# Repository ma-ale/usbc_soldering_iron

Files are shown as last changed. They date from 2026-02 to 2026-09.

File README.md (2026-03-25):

# USB-C Soldering Iron

Repo for a cool usb-c soldering iron that uses C245 cartridges and power up to 130W.

Read the [project report](doc/report/README.md) (in italian).

# IDEAS

* USB-C connector on the edge of the PCB like the [alientek T90B](https://youtu.be/Xl0IKpvlF3Y?si=ecKIGLwI0vSPZbJ4&t=7) (clamping plate)
* OLED Screen on a separate PCB, same project with a V-Cut
* More compact tip recess, stabilized by a, aluminium ring, maybe bought at the hardware store
* Single screw disassembly
* 13mm grip dimensions and 18mm otherwise
* 1mm walls in PETG
* Add a ~small~ button to the bootsel line

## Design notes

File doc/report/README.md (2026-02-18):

# Project Report

Obbiettivi:

- Supporto USB PD 3.1 e EPR per una potenza massima di 130W@28V.
- Usare un filtro per rimanere al di sotto dei 5A massimi che supporta lo standard.
- Usare le [cartucce C245](CARTRIDGE.md) della JBC e compatibili.
- Mantenere la scheda sotto i 10x10mm di dimensioni per approfittare dei bassi costi di produzione.
- Creare una shell stampabile in 3D.

## Progetti Simili

- [EJ-Sil](https://github.com/Ralim/IronOS/discussions/2080): usa le punte del pinecil e la differenza principale è l'utilizzo di mosfet a canale n per lo switching della punta.
- [Arduino Soldering Station](https://www.instructables.com/DIY-Arduino-Soldering-Station/): progetto di GreatScott, si alimenta dalla tensione di rete e usa i manici JBC e punte C245.
- [Unisolder](http://dangerousprototypes.com/forum/index.php?topic=7218.0): stazione completamente universale per molteplici tipi di punte, anche questa da banco.
- [Axxsolder](https://github.com/nx6110a5100/Stm32-jbc-solder-station): stazione portatile, alimentabile anche con usb-c ma a 60W massimi, compatibile con punte C245 e C210.

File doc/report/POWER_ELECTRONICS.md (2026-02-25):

# Circuiteria di Potenza

La parte principale del saldatore è la parte di potenza.

## USB PD
Lo standard USB PD e EPR permette potenze di uscita fino a 280W, il problema è che l'aumento di potenza viene ottenuto solamente con un aumento di tensione, mantenendo la corrente massima a 5A:
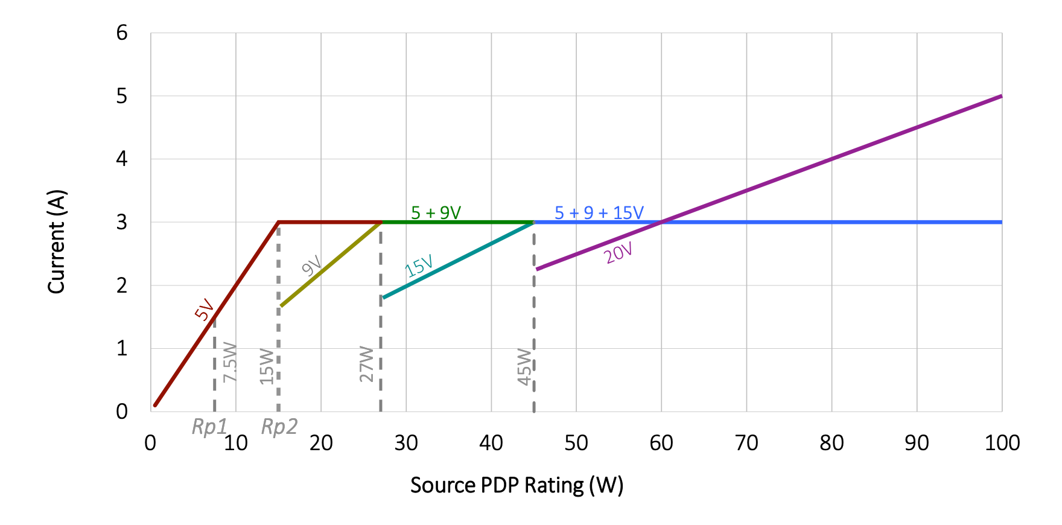
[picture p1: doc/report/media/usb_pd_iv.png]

Quindi per mantenere la potenza di ingresso al di sotto del rating dell'alimentatore è necessario mantenere la corrente al di sotto dei 5A, superare i 5A (o poco più) manderebbe l'alimentatore in protezione spengendolo.
La maggior parte dei saldatori commerciali USB non hanno nessun tipo di filtraggio, invece usano diversi trucchi:

1. Punte non standard a 5Ohm, come il [Sequre S99](https://sequremall.com/products/sequer-s99-soldering-iron-support-pd-qc-dc-pps-power-supply-compatible-with-c245-tip-for-drone-rc-model-welding-repair-tool-anti-stat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).
2. Switching molto veloce.
3. Limitano la tensione di ingresso per rimanere sotto al limite di corrente, limitando anche la potenza.
4. Se ne fregano il cazzo e sperano che l'alimentatore se ne freghi anch'esso.

## Monitoring della Potenza di Uscita

Tocca leggere sia la tensione che la corrente, per la lettura della tensione basta un partitore resistivo:
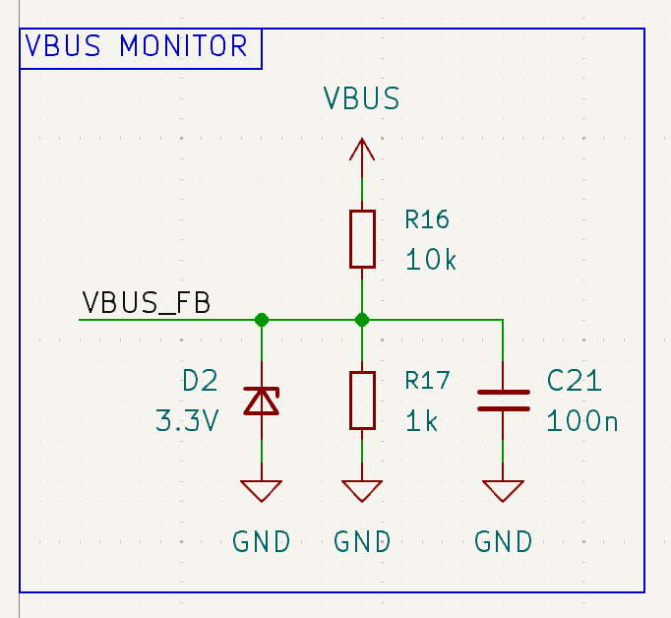
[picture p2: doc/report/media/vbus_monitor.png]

Mentre per la lettura della corrente conviene usare un monitor high-side, in modo da non disturbare la trensione di terra e quindi le misure della termocoppia. Questi amplificatori devono essere fatti apposta per sopportare la tensione a modo comune alta, pari alla tensione di alimentazione.
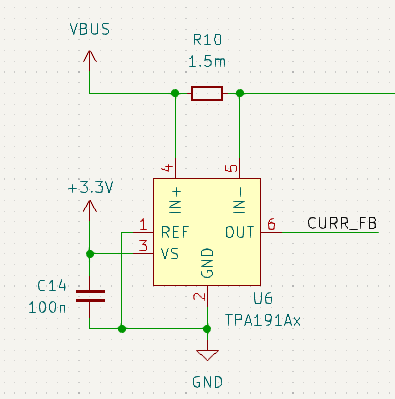
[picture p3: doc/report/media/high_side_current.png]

Questo tipo di monitoring si può fare in diversi modi:

1. Con un amplificatore operazionale discreto, ma questo porta il numero di componenti ad almeno 5, contando condensatore di bypass e resistenza di uscita sono 7.
2. Con un integrato con uscita di corrente come lo [ZXCT1109](https://www.diodes.com/part/view/ZXCT1109), che però ha una uscita in corrente che per essere letta correttamente dovrebbe essere bufferata.
3. Con un integrato con uscita in tensione come lo [TPA191](https://static.3peak.com/res/doc/ds/Datasheet_TPA191.pdf), in questo caso non serve resistenza di gain e basta attaccarlo al pin di ADC del micro.
4. Usar un integrato con uscita digitale come lo [INA230](https://www.ti.com/lit/ds/symlink/ina230.pdf) o l'[INA226](https://www.ti.com/lit/ds/symlink/ina226.pdf), che integra sia il monitoring di tensione che quello di corrente, però il costo è molto più alto.

Analisi costo/area:

- INA226: 0.61 EUR, solo area di un MSOP-10, non poca ma tutto in uno.
- TPA191 + 1k.1% + 10k.1% + Zener: 0.57 EUR, area 3x0603+SOD-323+SOT-23-6, leggermente maggiore ma migliore flessibilità sul piazzamento.

Per evitare di comprare altri componenti e aumentare inutilmente il costo dell'ordine è meglio usare il [INA226](https://www.ti.com/lit/ds/symlink/ina226.pdf) o il suo equivalente [TPA626](https://www.lcsc.com/product-detail/C5761471.html). Inoltre questi integrati permettono di impostare alert per la sovraccorrente o sovratensione.
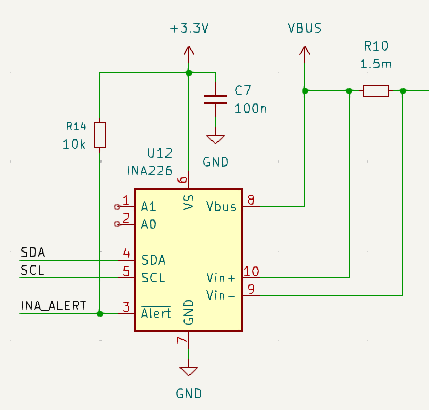
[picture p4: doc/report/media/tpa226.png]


## Mosfet e Filtro Pi
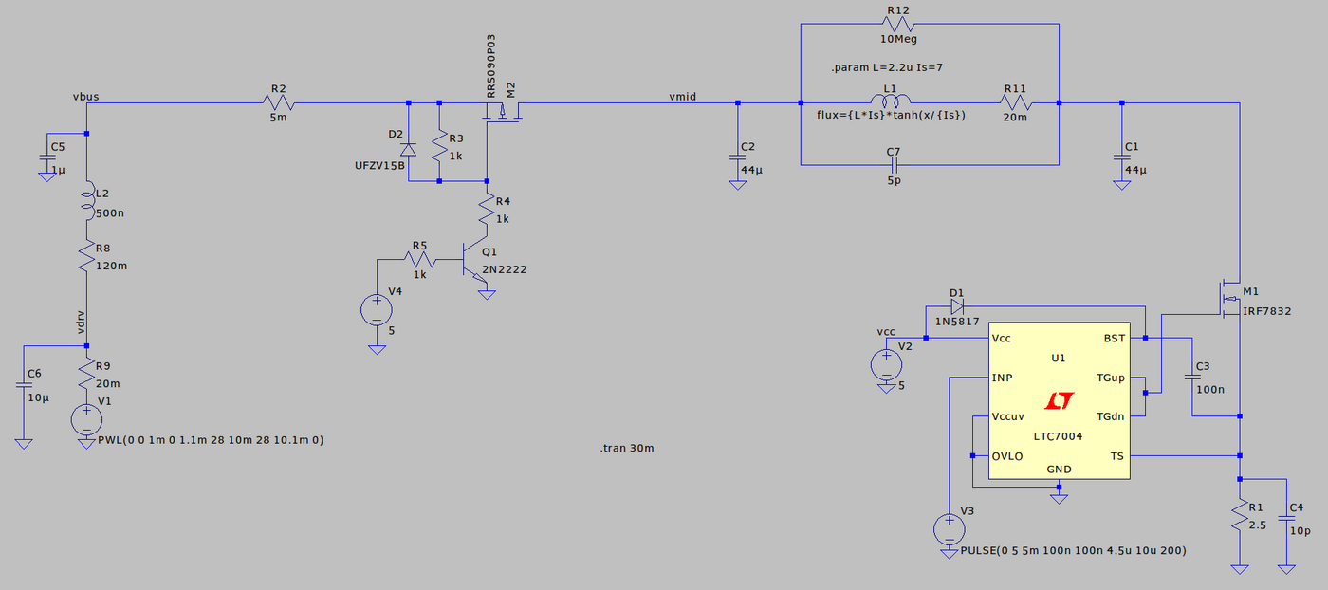
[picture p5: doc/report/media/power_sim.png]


Quello che importa è avere una corrente costante dal lato di ingresso, siccome la punta è un carico resistivo mi importa poco se riceve picchi di tensione e corrente. Per questo motivo il modo più semplice di smussare la corrente al lato di ingresso è di usare un [filtro PI](https://resources.altium.com/it/p/pi-filter-designs-power-supplies):
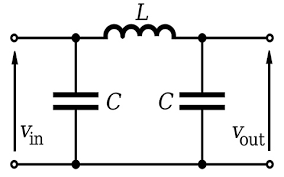
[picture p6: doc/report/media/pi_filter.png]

La frequenza di taglio del filtro PI è la solita di un filtro LC:
$$
f_0 = \frac{1}{2\pi\sqrt{L\ 2C}}
$$
Allora per ottenere il comportamento desiderato la frequenza di switching della punta deve essere almeno una decade sopra questo valore.
$$
L=2.2\mu \text{H},\ C=44\mu \text{F} \\ f_0 = 11.4\text{kHz}
$$
La frequenza di switching va anche valutata in base alle perdite di switching sul mosfet.

A differenza di [altre soluzioni](#altre-soluzioni), un filtro di questo tipo è di bassissima complessità e non richiede un particolare controllo, l'importante è usare la giusta frequenza di switching e limitare la potenza alla punta per garantire che la corrente rimanga nel limite. 

### Scelta dell'Induttore

Le specifiche principali dell'induttore per questa applicazione sono:

- Dimensione, la scheda è in alcune sezioni di 10mm di larghezza, quindi sarebbe meglio tenersi sotto i 6x6mm.
- ESR (Equivalent Series Resistance), ci dice quanto dissiperà l'induttore, inversamente proporzionale a dimensione e all'induttanza.
- Corrente di saturazione, la corrente per la quale il core dell'induttore satura, superare questa corrente riduce l'induttanza effettiva e scalda il core.
- Corrente di riscaldamento, la corrente per cui l'induttore comincia a scaldarsi sopra una certa temperatura se l'aria è a 25 gradi, ci dice la resistenza termica del package.

Alcuni induttori considerati, in **bold** quelli buoni:
| **MODELLO** | **VALORE** | **DCR** | **PACKAGE** |
| --- | --- | --- | --- |
| [XAL6060-103MEC](https://www.lcsc.com/product-detail/C5329540.html) | 10u | 27m | 6.6x6.4 |
| [XRFWHP0660A-100M](https://www.lcsc.com/product-detail/C51913009.html) | 10u | 30m | 6.6x6.4 |
| [AAPS0660M100F](https://www.lcsc.com/product-detail/C49261494.html) | 10u | 30m | 6.6x6.4 |
| [XRFWHP0660A-4R7M](https://www.lcsc.com/product-detail/C51913007.html) | 4.7u | 15m | 6.6x6.4 |
| [APH0660C-4R7M-TCD5](https://www.lcsc.com/product-detail/C50326286.html) | 4.7u | 15m | 6.6x6.4 |
| [AAPS0660M4R7F](https://www.lcsc.com/product-detail/C49261490.html) | 4.7u | 15m | 6.6x6.4 |
| [APS0660M4R7F](https://www.lcsc.com/product-detail/C49261301.html) | 4.7u | 15m | 6.6x6.4 |
| **[FC-ALX 4030D-2R2MT](https://www.lcsc.com/product-detail/C5370906.html)** | **2.2u** | **11m** | **4.2x4.2** |
| [MTQH404030S2R2MBT](https://www.lcsc.com/product-detail/C50345893.html) | 2.2u | 23m | 4.2x4.2 |
| [PSTMAA4030-2R2MG](https://www.lcsc.com/product-detail/C45385247.html) | 2.2u | 22m | 4.2x4.2 |
| [XRIM404030S2R2MGCA](https://www.lcsc.com/product-detail/C39846868.html) | 2.2u | 19m | 4.2x4.2 |
| [FC-ALX 5030D-3R3MT](https://www.lcsc.com/product-detail/C5370911.html) | 3.3u | 17m | 5.3x5.1 |
| [FC-ALX 5030D-2R2MT](https://www.lcsc.com/product-detail/C5370910.html) | 2.2u | 12m | 5.3x5.1 |

### Scelta dei Condensatori

[Derating](https://www.microtype.io/blog/dc-bias-effect-in-ceramic-capacitors) per DC bias.
[Modelli](https://product.tdk.com/en/technicalsupport/tvcl/general/mlcc.html) fatti bene della TDK. [Modelli](https://www.chemi-con.co.jp/en/faq/detail.php?id=How2LTspice) della Chemicon.

### Corrente di Inrush
### MOSFET e Driver

La scelta dei mosfet è fondamentale per ridurre la potenza dissipata, per semplificare il sistema ho scelto di usare uno [switching high-side](https://techweb.rohm.com/product/power-device/switches/23727/), mentre per ridurre le perdite sul mosfet ho deciso di usare un canale N. 
I mosfet canale N hanno resistenza di canale minore e minore carica di gate, quindi permettono di minimizzare sia le perdite di conduzione che le perdite di commutazione. Il problema è che usare un mosfet a canale n in configurazione high side richiede un driver fatto apposta.

Le perdite a causa della conduzione del mosfet si calcolano con l'espressione:
$$
P_\text{cond} = \frac{I^2}{R_{\text{DS}_\text{on}}} D
$$
Dove $I$ è la corrente che scorre nel mosfet quando acceso, approssimabile come $I=V_\text{BUS}/R_\text{tip}$, $T$ è il periodo di commutazione e $D$ è il duty cycle.

    NOTA: si arriva ad una espressione migliore se si considera che pure D dipende dalla potenza che voglio alla punta

Mentre la potenza persa durante la commutazione è stimabile come:
$$
P_\text{SW} = \frac{I\ V_{\text{BUS}}\ t_{\text{SW}}\ f}{2}
$$
Dove $t_\text{SW} = t_r + t_f$ è la somma del tempo di commutazione alto e basso del mosfet, si ricava dalla corrente di uscita del driver e dalla carica di gate del mosfet.

Lista di MOSFET canale n buoni:
|**MODELLO**|**VDS**|**RDSon**|**Qg [C]**|
|---|---|---|---|
|[AGM6014AP](https://www.lcsc.com/product-detail/C6719405.html)|60|4.3m|33n|
| [CSD18543Q3A](https://www.lcsc.com/product-detail/C840100.html) | 60 |  8.1m  |  11.1n |
| [AGM403AP](https://www.lcsc.com/product-detail/C7466527.html) |  40  | 2.7m | 10n |
| [AGM312AP](https://www.lcsc.com/product-detail/C22364314.html) | 30 | 9m | 4.1n |
| [AON7544](https://www.lcsc.com/product-detail/C315567.html) | 30 | 5m | 22.5n |
| [60N04D](https://www.lcsc.com/product-detail/C7543822.html) | 40 | 6.9m | 5.8n |
| [HD304N070SG](https://www.lcsc.com/product-detail/C50132379.html) | 40 | 6.5m | 16n |
| [TMG0069N04DF](https://www.lcsc.com/product-detail/C19189166.html) | 40 | 6.9m | 5.8n |
| [DOZ55N04](https://www.lcsc.com/product-detail/C42420928.html) | 40 | 5m | 19.5n |

Lista di driver buoni e non:
| **LINK** | **NOTE** | **PACKAGE** | **DIODO BOOT** |
| --- | --- | --- | --- |
| https://www.lcsc.com/product-detail/C5795658.html | half bridge, consigliato per notebook e quindi tensione minore | dfn 2x2 |  |
| https://www.lcsc.com/product-detail/C116731.html | half bridge per buck | dfn 2x2 |  |
| https://www.lcsc.com/product-detail/C892859.html | half bridge per buck | dfn 2x2 |  |
| https://www.lcsc.com/product-detail/C606336.html | half bridge per buck | dfn 3x3 |  |
| https://www.lcsc.com/product-detail/C533032.html | low-side ma anche high-side con configurazione strana, input differenziale | sot 23 |  |
| https://www.lcsc.com/product-detail/C5481755.html | high e low-side per mosfet SiC, input differenziale e configurazione strana | sot 23 |  |
| https://www.lcsc.com/product-detail/C964602.html | half bridge per buck | dfn 2x2 | interno |
| https://www.lcsc.com/product-detail/C2677203.html | logica 5V | sot 23 | esterno |
| **[IRS10752LTRPBF](https://www.lcsc.com/product-detail/C126923.html)** |  | sot 23 | esteno |
| [IRS20752LTRPBF](https://www.lcsc.com/product-detail/C495818.html) |  | sot 23 | esterno |
| [IRS25752LTRPBF](https://www.lcsc.com/product-detail/C538346.html) |  | sot 23 | esterno |
| **[NSG10752](https://www.lcsc.com/product-detail/C41414522.html)** | pin-compatible con quelli infineon | sot 23 | esterno |
| https://www.lcsc.com/product-detail/C603811.html | half-bridge per buck, discontinuato | dfn 2x2 | interno |
| https://www.lcsc.com/product-detail/C603810.html | half bridge per buck, versione di replacement per NCP81161 | dfn 2x2 | interno |
| https://www.lcsc.com/product-detail/C2677131.html | half bridge per buck | dfn 3x3 | interno |
| https://www.lcsc.com/product-detail/C41414473.html | half bridge per buck | dfn 3x3 | esterno |
| https://www.lcsc.com/product-detail/C154581.html | half bridge per buck | dfn 3x3 | interno |

Il problema dei driver selezionati è che hanno una UVLO molto alta (10V) che quindi richiede un buck ulteriore per alimentarli, aumentando il costo e numero dei componenti.

## Altre Soluzioni

## Altri Saldatori

È comodo confrontare altri saldatori USB-C e vedere come funzionano.

### Pinecil V2
Link alla [wiki](https://wiki.pine64.org/wiki/Pinecil), [schema elettrico](https://files.pine64.org/doc/Pinecil/Pinecil_schematic_v2.0_20220608.pdf).

### Alientek T80P
[Teardown](https://www.reddit.com/r/soldering/comments/1cm03vg/jbc_style_usb_soldering_iron_roundup_teardown/ ), [issue di IronOS](https://github.com/Ralim/IronOS/issues/1945) con foto e lista componenti.

### Miniware TS21
[Teardown](https://www.reddit.com/r/soldering/comments/1kho3lc/miniware_ts21_disassemble/), [issue di IronOS](https://github.com/Ralim/IronOS/issues/2122) con componenti.

### Sequre S60P
[Teardown](https://community.element14.com/technologies/test-and-measurement/b/blog/posts/usb-c-soldering-iron-quick-review-sequre-s60) e dettagli dei componenti, [discusione su IronOS](https://github.com/Ralim/IronOS/discussions/1806).

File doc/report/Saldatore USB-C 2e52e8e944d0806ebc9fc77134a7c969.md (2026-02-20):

# Saldatore USB-C

- https://www.printables.com/model/1127227-gridfinity-alientek-t80t80p-tool-holder-5x1 modello di un holder gridfinity per il t80p, possibile usarlo per confrontare le dimensioni delle punte
- https://www.printables.com/model/1548831-miniware-ts21/files modello a dimensione vera di un ts21, utile per confrontare le dimensioni
- https://www.printables.com/model/1435424-sliding-box-for-miniware-ts21 case per ts21 con storage per punte

# Buck

- [https://www.monolithicpower.com/en/inductor-selector-tool](https://www.monolithicpower.com/en/inductor-selector-tool)
- [Selecting Inductors for Buck Converters](https://www.ti.com/lit/an/snva038b/snva038b.pdf?ts=1769296550256)
- https://it.wikipedia.org/wiki/Convertitore_buck

i.sstatic.net

## Versione con Buck Discreto

Una soluzione sarebbe di costruire un buck sincrono con componenti discreti

[Basic Calculation of a Buck Converter's Power Stage](https://www.ti.com/lit/an/slva477b/slva477b.pdf?ts=1769211977943)

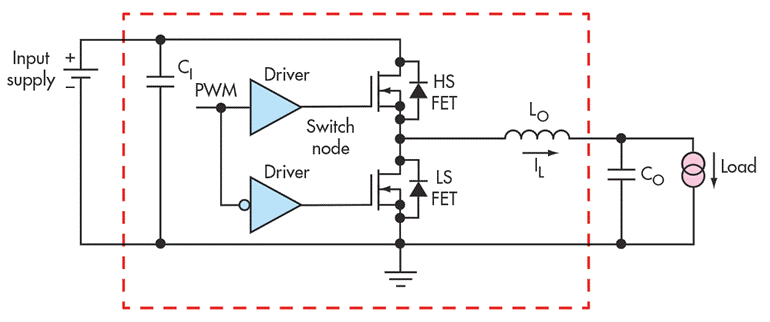
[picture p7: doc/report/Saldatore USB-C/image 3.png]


### MOSFET

Meglio usare un doppio mosfet integrato in configurazione half-bridge. Esistono tipi con due N-MOS e tipi con P-MOS e N-MOS. La versione con due N-MOS è la migliore in termini di efficienza ma richiede necessariamente un driver particolare con circuito di bootstrap.

Alcuni MOSFET:

- https://www.lcsc.com/product-detail/C155503.html
- https://www.lcsc.com/product-detail/C3289384.html
- https://www.lcsc.com/product-detail/C485677.html
- https://www.lcsc.com/product-detail/C464808.html
- https://www.lcsc.com/product-detail/C269268.html

### Driver

Esistono diversi driver, per questo caso servono driver o half-bridge oppure apposta per buck sincroni, il primo richiede due segnali PWM per controllare ognuno dei mosfet separatamente, mentre il secondo accetta un solo segnale PWM.

Una specifica importante è la corrente di uscita che determina il tempo di switching dei mosfet. Vedi [questa presentazione](https://www.mouser.com/pdfdocs/Selecting-Gate-Driver-Tutorial.pdf) per capire di cosa si parla, ma deriva dalla velocità con cui si riempie la capacità di gate. 

Alcuni Driver:

- https://www.lcsc.com/product-detail/C2676972.html https://www.lcsc.com/product-detail/C460680.html
- [IR3537 / CHL8510](https://www.lcsc.com/datasheet/C537661.pdf)
- https://www.lcsc.com/product-detail/C603956.html?s_z=n_NCV51511

## Versione con Buck Integrato

Si può usare un buck integrato (switch e controllore) e regolare la tensione di feedback con il microcontrollore, ottenendo la tensione che volgio io.

https://www.youtube.com/watch?v=hyLYPu-4EN8

Non è una cosa troppo comune ne tanto facile da fare, alcuni dicono che con l’ADC del micro non si va da nessuna parte, altri dicono di si ma di usare un ADC in corrente. Alcuni riferimenti:

- https://forum.allaboutcircuits.com/threads/digitally-controlled-buck-converter.75554/
- https://www.ednasia.com/use-a-current-mirror-to-control-a-power-supply/
- https://electronics.stackexchange.com/questions/700494/mcu-controlled-buck-converter-ic

Uno dei problemi di questo approccio è che i buck commerciali, anche di alta potenza sono fatti per essere “buoni”, poco ripple e tensione molto precisa. Mentre qello che serve a me è di rimanere sotto la potenza nominale impostata, quindi è molto overkill. Inoltre molti dei buck di alta potenza usano molti componenti di contorno aumentando ancora il prezzo.

Ricerca su Gemini: https://gemini.google.com/app/65933a590936e3ec

Lista di buck fighi:

- [SiC461](https://www.lcsc.com/datasheet/C499531.pdf) la Vishay ha addirittura un calcolatore fatto apposta: https://vishay.transim.com/landing
- [~~SY8308~~](https://www.lcsc.com/datasheet/C7427429.pdf) https://www.lcsc.com/product-detail/C125897.html, https://www.lcsc.com/product-detail/C207642.html
- [AOZ2261AQI](https://www.lcsc.com/datasheet/C2071876.pdf)
- [XR76203](https://www.lcsc.com/datasheet/C555356.pdf) da usare il [xr76208](https://www.lcsc.com/product-detail/C555356.html?s_z=n_xr76208)
- https://www.lcsc.com/product-detail/C3188410.html [Datasheet in inglese](https://www.ti.com/lit/ds/symlink/lm61495-q1.pdf?ts=1770121316572)
- [NDP13802QB](https://www.lcsc.com/datasheet/C7420577.pdf) oppure https://www.lcsc.com/product-detail/C7420585.html?s_z=n_ndp1480
- [TPS56837Hx](https://www.ti.com/lit/ds/symlink/tps56837h.pdf?ts=1769345326940) …HA non ha il discharge ma costa di più

Saldatori che usano questo metodo: 

- Solder ninja pen, [hardware](https://github.com/sitronlabs/Solder-Ninja-Pen-Electronics), [software](https://github.com/sitronlabs/Solder-Ninja-Pen-Firmware), [ironos](https://github.com/Ralim/IronOS/issues/1989). Soli 45W ma usa un buck integrato [TPS621351](https://www.lcsc.com/product-detail/C2070706.html?s_z=n_TPS621351) quindi il software di controllo è quello. Usa questo DAC ([DAC5311](https://www.lcsc.com/product-detail/C191582.html?s_z=n_DAC5311)) per controllare il feedback del buck.
- [iFixit Hub](https://www.ifixit.com/Device/iFixit_Soldering) le [schematic](https://www.ifixit.com/Document/WOhhObf5OxsyA4Xh/ES-SI-2100-R15.pdf?referrer=wiki%3A570611) sono pubbliche, 100W ma dalle recensioni non sembra arrivarci davvero. Usa un [MP2329](https://www.monolithicpower.com/en/mp2329.html) buck fino a 20V di Vin e il dac integrato dell’STM32 per controllare il feedback. Le dimensioni del controllore sono piccole, forse per questo non riesce ad arrivare ai 100W senza andare in protezione.

## Versione con Half-Bridge e Micro

La differenza di questo approccio è l’uso di un half-bridge che però ha anche integrato il driver per i mosfet. In questo modo l’interità del controllo deve essere fatta dal microcontrollore però si risparmia sulle feature inutili e tutti i componenti di contorno che ne vengono.

Alcuni MOSFET:

- https://www.lcsc.com/product-detail/C3654920.html?s_z=n_SiC641

Ricerca su Gemini: https://gemini.google.com/app/7377e4ba09fedab9

Calcolo dell’efficienza:

- https://fscdn.rohm.com/en/products/databook/applinote/ic/power/switching_regulator/buck_converter_efficiency_app-e.pdf
- https://www.ti.com/lit/an/slvaeq9/slvaeq9.pdf?ts=1769284164843&ref_url=https%253A%252F%252Fwww.google.com%252F
- https://www.hajim.rochester.edu/ece/sites/friedman/papers/ICECS_10.pdf

## Buck Multifase

Per ridurre il picco di corrente dall’ingresso bisogna necessariamente aggiungere più buck in parallelo. 

https://www.ti.com/lit/an/slva882b/slva882b.pdf

Il picco di corrente di un buck è pari alla corrente media di uscita più la metà del ripple di corrente, che per design è maggiore al 40%. Quindi a livello di corrente di picco non si è migliorato nulla.

Nel buck multifase il picco di corrente è diviso per il numero di fasi, quindi per me ne bastano due.

L’implementazione di un buck multifase, per essere abbastanza compatta, deve essere fatta o con power stage integrati controllati dal microcontrollore, o in modo discreto con mos e driver. Ho scelto mos e driver 2x2mm.

alcuni n-mos doppi:

- [UT6K3](https://www.lcsc.com/datasheet/C5336512.pdf)
- [AON7934](https://www.lcsc.com/datasheet/C485677.pdf)
- [IRLHS6376TRPBF](https://www.lcsc.com/datasheet/C538153.pdf)
- [SiA918EDJ](https://www.lcsc.com/datasheet/C727447.pdf)

Alcuni gate driver:

- [BDR2L00](https://www.lcsc.com/datasheet/C5371998.pdf)
- [NCP81161](https://www.lcsc.com/datasheet/C603811.pdf) [NCP81151](https://www.lcsc.com/datasheet/C603810.pdf)
- https://www.lcsc.com/product-detail/C41414784.html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

# Filtro Pi per Ridurre i Picchi di Corrente

Non serve allora che si usi nessun tipo di controllore, basta che la frequenza di PWM della parte switching sia maggiore della frequenza di taglio del filtro.

Si risparmia in termini di spazio perchè basta un mosfet e il suo driver, allora posso rendere l’induttore più grande e usare pochi condensatori. Inoltre in termini di controllo è molto molto più sempplice, si risparmia su DAC, resistenze di precisione e altri componenti particolari. Essendo un solo NMOS allora anche la dissiapzione è minore e le perdite switching possono essere piccole rispetto al buck dato che la frequenza di switching rimane sulle decine di kHz.

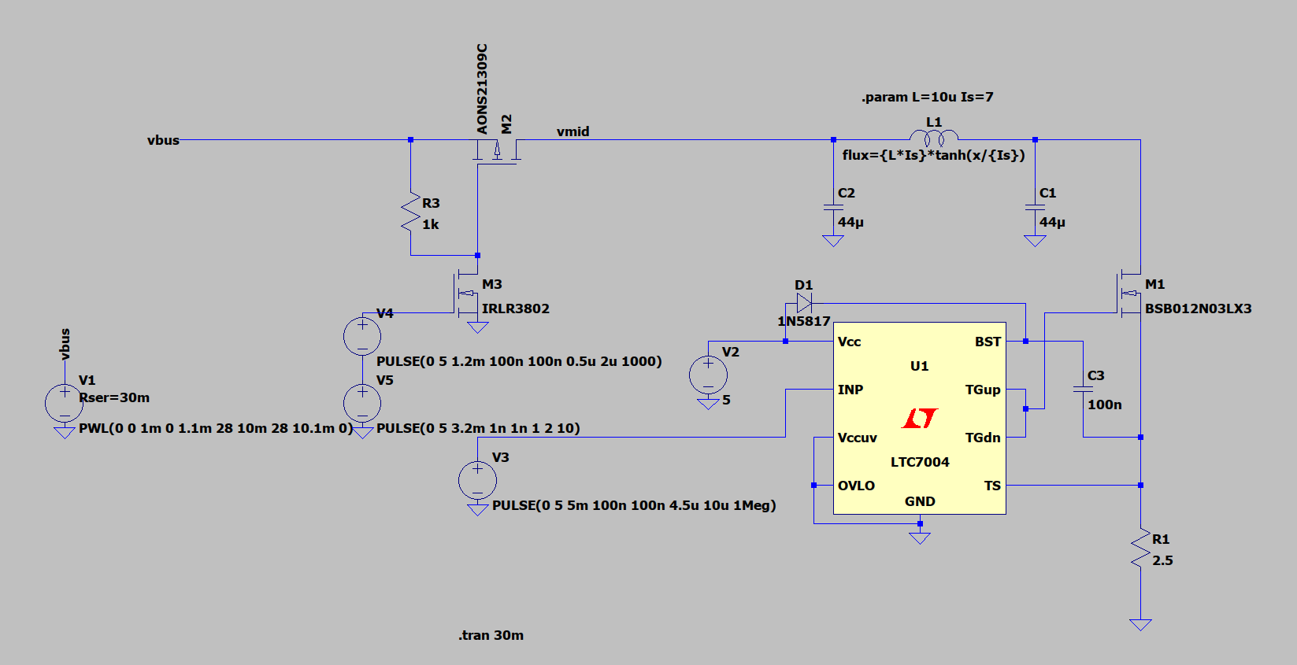
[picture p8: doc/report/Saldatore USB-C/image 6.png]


### Induttori

Un problema è la corrente di inrush che spengerebbe l’alimentatore, quindi bisogna attivamente limitare la corrente ed effettuare un soft-start. Esistono vari integrati fatti apposta.

Integrati per protezione di inrush (efuse, hotswap controllers, etc.):

- [MX26631DL](https://www.lcsc.com/datasheet/C18197523.pdf)
- https://www.ti.com/product/TPS2663
- [DPS1135](https://www.diodes.com/datasheet/download/DPS1135.pdf) https://www.lcsc.com/product-detail/C2150216.html?s_z=n_DPS1135
- https://www.maxinmicro.com/products/dzbxs/wzgl
- https://www.lcsc.com/product-detail/C47967144.html?s_z=n_LMX5069DL
- [RT1720](https://www.lcsc.com/datasheet/C147997.pdf)
- [TPS249x](https://www.lcsc.com/datasheet/C273636.pdf)
- [TPS25980](https://www.ti.com/lit/ds/symlink/tps25980.pdf?ts=1770547961735)

**Switch per Input Side:**

- https://www.lcsc.com/product-detail/C5219206.html?s_z=n_LM74502

### Condensatori

https://article.murata.com/en-eu/article/temperature-characteristics-electrostatic-capacitance

| https://www.lcsc.com/product-detail/C47117456.html |  |  |
| --- | --- | --- |
| https://www.lcsc.com/product-detail/C338080.html |  |  |
| https://www.lcsc.com/product-detail/C6119901.html |  |  |
| https://www.lcsc.com/product-detail/C22367832.html |  |  |

# Altri Componenti

### Bottoni

| https://www.lcsc.com/product-detail/C963235.html |  |  |
| --- | --- | --- |
| https://www.lcsc.com/product-detail/C2906288.html |  |  |
| https://www.lcsc.com/product-detail/C778158.html |  |  |
| https://www.lcsc.com/product-detail/C49234146.html |  |  |
| https://www.lcsc.com/product-detail/C393942.html |  |  |
| https://www.lcsc.com/product-detail/C79167.html |  |  |
| https://www.lcsc.com/product-detail/C2906288.html |  |  |

### Induttori per regolatore 3.3V

| **MODELLO** | **PACKAGE** | **AMP RATING** | **DCR** |
| --- | --- | --- | --- |
| https://www.lcsc.com/product-detail/C486332.html | 0805 | 550mA | 270mΩ |
| https://www.lcsc.com/product-detail/C48689504.html | 1008 | 1.4A | 270mΩ |
| https://www.lcsc.com/product-detail/C52741389.html | 1008 | 1A | 380mΩ |
| https://www.lcsc.com/product-detail/C52741377.html | 0806 | 820mA | 545mΩ |
| https://www.lcsc.com/product-detail/C5289257.html | 1008 | 520mA | 810mΩ |
| https://www.lcsc.com/product-detail/C52741450.html | 1008 | 1.1A | 320mΩ |
| https://www.lcsc.com/product-detail/C53198536.html | 1008 | 1.6A | 245mΩ |
| https://www.lcsc.com/product-detail/C216121.html | 0806 | 700mA | 500mΩ |
| https://www.lcsc.com/product-detail/C5451617.html | 1008 | 1.05A | 360mΩ |
| https://www.lcsc.com/product-detail/C602017.html | 1008 | 1.1A | 305mΩ |
| https://www.lcsc.com/product-detail/C601999.html | 0806 | 820mA | 500mΩ |
| https://www.lcsc.com/product-detail/C5832375.html | 1008 | 1.6A | 245mΩ |
| https://www.lcsc.com/product-detail/C5832361.html | 1008 | 1.6A | 270mΩ |

### Encoder

| **MODELLO** | **SWITCH** | **DIMENSIONE** |
| --- | --- | --- |
| https://www.lcsc.com/product-detail/C17702124.html | si | 4.8x3.9x3.5 |
| https://www.lcsc.com/product-detail/C49302686.html | no | 4.8x3.9x2.9 |
| https://www.lcsc.com/product-detail/C52995052.html | no | 4.8x3.9x2.9 |
| https://www.lcsc.com/product-detail/C52995053.html | no | 4.8x3.9x2.9 |
| https://www.lcsc.com/product-detail/C41430892.html https://www.lcsc.com/product-detail/C46818248.html https://www.lcsc.com/product-detail/C2925423.html | si |  |
| https://www.lcsc.com/product-detail/C125039.html |  |  |

Doveviene usato l’encoder che mi piace:

- https://www.instructables.com/Arduino-Walkie-Talkie/
- https://www.reddit.com/r/embedded/comments/1qjdnbd/early_build_of_ui_for_midi_pedal_adapter_im_making/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
- https://flatfootfox.com/the-typeboy-mk-ii/
- https://github.com/Architeuthis-Flux/JumperlessV5/tree/main/Jumperless23V50/Footprints%20and%20Symbols/JumprlessFootprints.pretty

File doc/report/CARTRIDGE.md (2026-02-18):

# Cartucce C245

La punta scelta è la [JBC C245](https://www.jbctools.com/c245-cartridge-range-long-life-tip-product-19-design-iron.html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), sono cartucce con integrata sia la resistenza che una termocoppia.
I motivi di questa scelta sono:

1. Sono punte molto comuni, sia nei saldatori USB-C che in stazioni compatibili.
2. Esistono vari cloni delle punte di marche cinesi, abbassando il costo all'utente.
3. Ci sono tanti diversi formati delle punte, da molto fine per SMD fino a scalpelli molto grandi.
4. Potenza massima di 130W, che è abbastanza alta per saldare quasi ogni cosa.

## Dettagli sulle Cartucce
[Taglio di una cartuccia](https://web.archive.org/web/20161018130611/http://bbs.38hot.net/thread-28591-1-1.html) originale, da un forum cinese, mostra i contatti e come è formata la termocoppia.

### Contatti
I contatti della punta sembrano essere [questi](http://adgd.ru/2021/01/04/jbc-soldering-cartridges-pinouts/). Non capisco però perchè diversi saldatori collegano la cartuccia in modo diverso.
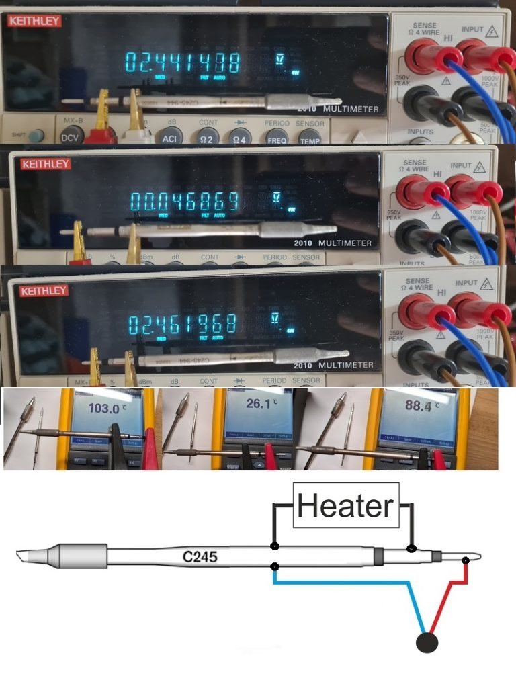
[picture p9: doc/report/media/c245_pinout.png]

La resistenza delle cartucce è di circa 2,5Ohm come si vede dalla foto, ma a seconda del tipo di punta e del produttore questo valore cambia molto, fino a 5Ohm per delle cartucce non standard.

Sul forum di eevblog ci sono vari thread che parlano di queste punte, [eccone uno](https://www.eevblog.com/forum/projects/jbc-handle-cartridge-data/25/) che parla della resistenza, contatti e specifiche della termocoppia. Uno [solamente sulla termocoppia](https://www.eevblog.com/forum/projects/how-do-soldering-tips-work-i-cannot-find-any-thermistor-or-thermocouple-inside/msg6109449/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).

### Dimensioni
Vorrei dire che le ho dovute fare io grrr.


## Contatti per le Cartucce
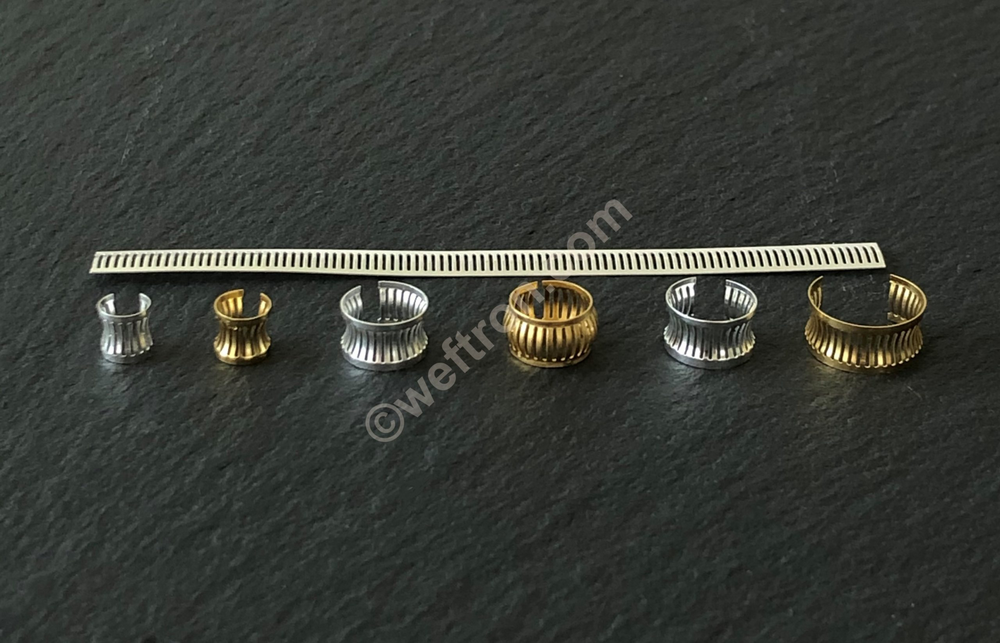
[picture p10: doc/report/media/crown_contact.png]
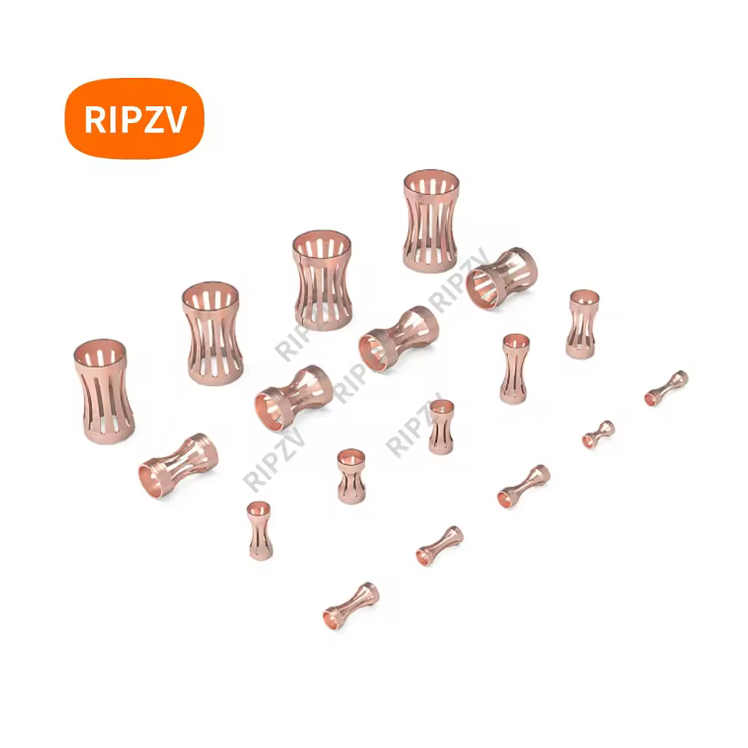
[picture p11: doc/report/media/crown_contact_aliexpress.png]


Esistono diversi tipi di contatti, divesi manici usano diverse soluzioni, ma tutti i prodotti recenti sembrano usare dei [contatti a banda](https://en.wikipedia.org/wiki/Electrical_connector#Crown_spring_connectors) (crown spring, louverband, crown contacts, ...). Questi sono solitamente prodotti custom e costano parecchio in piccole quantità.
Alcuni prodotti e produttori:

- https://yifengxing.en.made-in-china.com/product/VJNYECxvvlUG/China-Stamping-Wire-Drum-Spring-Terminals-Connector-Copper-Terminal-Crimp-Wire-Terminal-Block-Hardware-M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
- https://www.alibaba.com/product-detail/Reida-3-0-8-0-Beryllium_1600460847915.html
- https://it.aliexpress.com/item/1005006737028553.html
- https://www.te.com/en/product-192046-6.html
- https://www.te.com/en/product-1-192004-4.html
- https://it.aliexpress.com/item/1005009010705644.html
- https://it.aliexpress.com/item/1005010642796548.html
- https://www.joyelectric-china.com/insulation-components-for-gis/insulation-parts-and-accessories/louvered-contact-bands.html
- https://globetech.jp/products/contact-bands
- https://eu.mouser.com/c/connectors/?series=Louvertac&pg=2
- https://www.digikey.it/en/products/filter/backplane-connectors/backplane-connector-contacts/335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

Un modo per ottenere questi contatti è di cannibalizzarli dagli handle per le stazioni jbc, basta cercare "jbc handle c245" su aliexpress e si trovano diversi manici con contatti buoni. Un'altra fonte sono le schede per "DIY907", che sembrano essere schede di conversione da un saldatore 907 a cartucce C245:
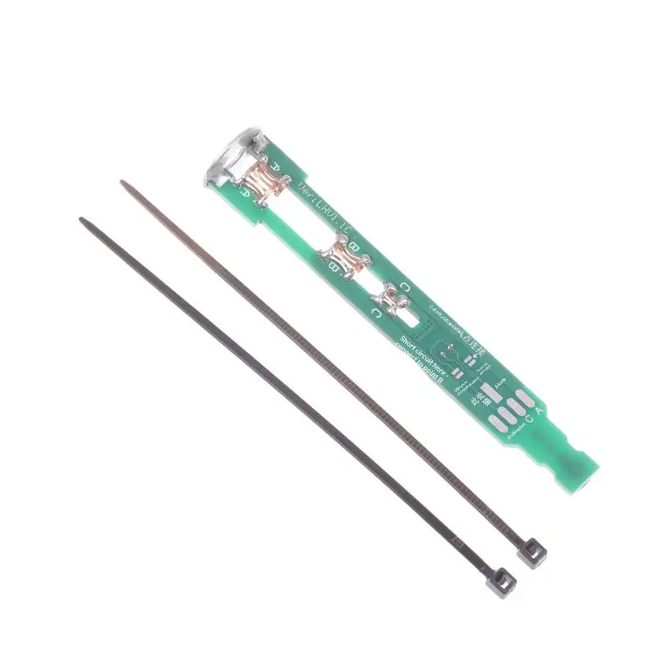
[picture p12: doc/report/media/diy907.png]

Il costo al 18/02/2026 si aggirava attorno ai 2,30eur.

Una alternativa è di creare dei tubicini in rame, crimparli poco e magari farci qualche taglietto, come ha fatto [questo tizo](https://www.youtube.com/watch?v=pcxZdMfctsA), [altro link](https://www.pcbway.com/project/shareproject/Fully_Portable_Battery_Soldering_Iron_670303fe.html).
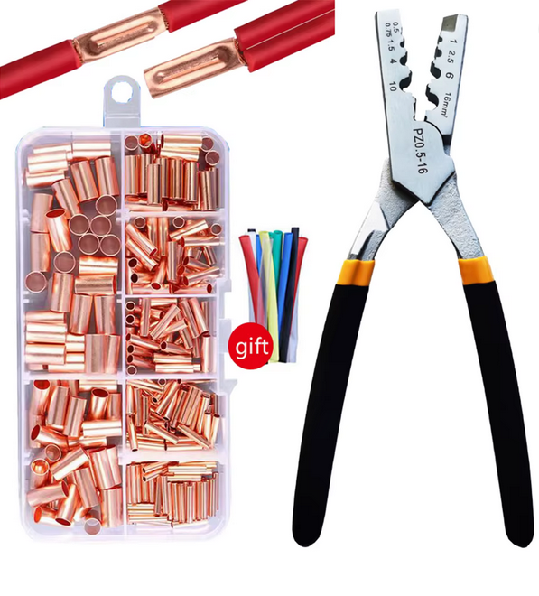
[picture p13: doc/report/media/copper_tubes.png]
 [link aliexpress](https://it.aliexpress.com/item/1005006967338748.html)

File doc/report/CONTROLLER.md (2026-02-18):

# Controllore

Il cuore della scheda è un [WCH CH32V203](https://www.wch-ic.com/products/CH32V203.html), che ha un core RISC-V a 240MHz e una PHY USB integrata.

## Controllo in Temperatura
Esistono diversi progetti simili, come [IronOS](https://github.com/Ralim/IronOS) che gira sul [Pinecil](https://pine64.com/product/pinecil-smart-mini-portable-soldering-iron/).
[Questo articolo](https://www.electronicdesign.com/technologies/analog/article/21773207/take-back-half-a-novel-integrating-temperature-control-algorithm) descrive un algoritmo di controllo di temperatura.

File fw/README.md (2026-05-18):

# USB-C Soldering Iron Firmware

```
SHRIM
   __-------._
_`   __===O~O_\.
   / \ _ __w_=
  /___ /~^
 |    |~^
  \ __\~^   \ V/
   \_ _\ __ / /
     `- __|_-'
```

## Special thanks to:

* cnlohr and all the contributors of [ch32fun][ch32fun]
* deftio for [FR_math][frmath] which I briefly used
* olkiarus for [u8g2][u8g2]
* The Swedish Institute of Computer Science for [protothreads][pt]

[ch32fun]: https://github.com/cnlohr/ch32fun
[frmath]: https://github.com/deftio/fr_math
[u8g2]: https://github.com/olikraus/u8g2
[pt]: https://dunkels.com/adam/pt/index.html

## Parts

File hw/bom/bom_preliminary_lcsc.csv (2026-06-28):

Index | LCSC# | MPN | Manufacturer | Package | Customer # | Description | RoHS | Quantity | MOQ | Multiple | Unit Price(€) | Extended Price(€) | Product Link
1 | C2827931 | SS24L | Guangdong Hottech | SOD-123FL |  | Diode Independent 40V 2A Surface Mount SOD-123FL | yes | 20 | 20 | 20 | 0.0238 | 0.48 | https://www.lcsc.com/product-detail/C2827931.html
2 | C5185587 | CUM1206-15FR004 | FORT | 1206 |  | 1W 4mΩ SMD ±50ppm/℃ Current Sense Resistor ±1% 1206 Current Sense Resistors RoHS | yes | 5 | 5 | 5 | 0.1011 | 0.51 | https://www.lcsc.com/product-detail/C5185587.html
3 | C38582720 | TPA191A4-SC6R | 3PEAK | SOT-363 |  | -300mV~36V 50uV 2.5V/us 30kHz 120dB 22uA 80uA 100V/V SOT-363 Instrumentation, Op Amps, Buffer Amps RoHS | yes | 5 | 5 | 5 | 0.3814 | 1.91 | https://www.lcsc.com/product-detail/C38582720.html
4 | C18723014 | X069-9616TSWIG02-H14 | Wisevision | - |  | 0.69 96x16 SSD1312 chip I2C LCD, OLED, Graphic RoHS | yes | 5 | 1 | 1 | 1.4487 | 7.24 | https://www.lcsc.com/product-detail/C18723014.html
5 | C5370906 | FC-ALX 4030D-2R2MT | FANGCHENG | SMD,4.2x4.2mm |  | 8.1A 2.2uH ±20% 8.1A 10.7mΩ Molded Inductor SMD,4.2x4.2mm Fixed Inductors RoHS | yes | 5 | 1 | 1 | 0.4984 | 2.49 | https://www.lcsc.com/product-detail/C5370906.html
6 | C2997487 | MPD220M1VD19040R | Ymin | SMD,7.3x4.3mm |  | 22uF 35V 3.2A@100kHz 40mΩ@100kHz ±20% SMD,7.3x4.3mm Aluminum - Polymer Capacitors RoHS | yes | 5 | 1 | 1 | 0.8800 | 4.40 | https://www.lcsc.com/product-detail/C2997487.html
7 | C29936 | CL10B105KA8NNNC | Samsung Electro-Mechanics | 0603 |  | 1uF ±10% 25V Ceramic Capacitor X7R 0603 | yes | 50 | 50 | 50 | 0.0199 | 1.00 | https://www.lcsc.com/product-detail/C29936.html
8 | C98192 | CL21A475KBQNNNE | Samsung Electro-Mechanics | 0805 |  | 4.7uF ±10% 50V Ceramic Capacitor X5R 0805 | yes | 10 | 10 | 10 | 0.0459 | 0.46 | https://www.lcsc.com/product-detail/C98192.html
9 | C41414522 | NSG10752 | WXNSIC | SOT-23-6 |  | High Side Gate Driver IC MOSFET IGBT SOT-23-6 | yes | 5 | 1 | 1 | 0.4925 | 2.46 | https://www.lcsc.com/product-detail/C41414522.html
10 | C46818248 | SIQ-02FVS3 | LZG | - |  | Encoders RoHS | yes | 5 | 1 | 1 | 1.0267 | 5.13 | https://www.lcsc.com/product-detail/C46818248.html
11 | C162670 | NCU18XH103F6SRB | muRata | 0603 |  | NTC Thermistor 10kΩ Surface Mount 0603 | yes | 10 | 10 | 10 | 0.0954 | 0.95 | https://www.lcsc.com/product-detail/C162670.html
12 | C19274408 | SC7A20HTR | Hangzhou Silan Microelectronics | LGA-12(2x2) |  | LGA-12(2x2) Accelerometers RoHS | yes | 5 | 1 | 1 | 0.2588 | 1.29 | https://www.lcsc.com/product-detail/C19274408.html
13 | C138714 | TPD4E05U06DQAR | TI | USON-10(1x2.5) |  | 14VC Clamp 2.5A@8/20us Ipp TVS DIODE USON-10(1x2.5) | yes | 5 | 5 | 5 | 0.0743 | 0.37 | https://www.lcsc.com/product-detail/C138714.html
14 | C2932326 | MT3608L | XI'AN Aerosemi Tech | SOT-23-6 |  | 1.2MHz Boost Adjustable 600mV~20V 2.5A SOT-23-6 Voltage Regulators - DC DC Switching Regulators RoHS | yes | 10 | 10 | 10 | 0.0398 | 0.40 | https://www.lcsc.com/product-detail/C2932326.html
15 | C4169844 | RS73F1JTTD2703B | KOA | 0603 |  | 200mW 270kΩ Thick Film Resistor ±25ppm/℃ ±0.1% 0603 Chip Resistor - Surface Mount RoHS | yes | 5 | 5 | 5 | 0.0667 | 0.33 | https://www.lcsc.com/product-detail/C4169844.html
16 | C2906999 | FRC0603F1803TS | FOJAN | 0603 |  | 180kΩ ±1% 100mW 0603 Thick Film Resistor | yes | 100 | 100 | 100 | 0.0020 | 0.20 | https://www.lcsc.com/product-detail/C2906999.html
17 | C7466527 | AGM403AP | AGMSEMI | PDFN3.3x3.3-8 |  | N-Channel 40V 65A 69W Surface Mount PDFN3.3x3.3 | yes | 5 | 5 | 5 | 0.2618 | 1.31 | https://www.lcsc.com/product-detail/C7466527.html
18 | C780769 | AP63203WU-7 | DIODES | TSOT-23-6 |  | 1.1MHz Step-down type Fixed 2A 3.3V TSOT-23-6 Voltage Regulators - DC DC Switching Regulators RoHS | yes | 5 | 1 | 1 | 0.5415 | 2.71 | https://www.lcsc.com/product-detail/C780769.html
19 | C42442062 | CH32X035F8U6 | WCH | QFN-20-EP(3x3) |  | RISC-V4C 32 Bit 48MHz 19 QFN-20-EP(3x3) Microcontrollers RoHS | yes | 5 | 1 | 1 | 0.4886 | 2.44 | https://www.lcsc.com/product-detail/C42442062.html
20 | C52754543 | RB521S30T1G-HXY | HXY MOSFET | SOD-523 |  | 1 Independent 30V 350mV@10mA 200mA SOD-523 Single Diodes RoHS | yes | 20 | 20 | 20 | 0.0190 | 0.38 | https://www.lcsc.com/product-detail/C52754543.html
21 | C473369 | TLV333IDBVR | TI | SOT-23-5 |  | 1 2uV 0.16V/us 102dB 70pA 17uA 350kHz Rail-to-Rail Input, Rail-to-Rail Output SOT-23-5 Instrumentation, Op Amps, Buffer Amps RoHS | yes | 5 | 1 | 1 | 0.3701 | 1.85 | https://www.lcsc.com/product-detail/C473369.html
22 | C110776 | RT0603BRD071KL | YAGEO | 0603 |  | 100mW 1kΩ 75V Thin Film Resistor ±25ppm/℃ ±0.1% 0603 Chip Resistor - Surface Mount RoHS | yes | 20 | 20 | 20 | 0.0268 | 0.54 | https://www.lcsc.com/product-detail/C110776.html
23 | C17701150 | MTQH201612S3R3MBT | MetalLions | 0806 |  | 2.4A 3.3uH ±20% 135mΩ 2.7A Magnetic Shielded Inductor 0806 Fixed Inductors RoHS | yes | 10 | 10 | 10 | 0.0384 | 0.38 | https://www.lcsc.com/product-detail/C17701150.html
24 | C41398747 | GT-TS201A-H0065-L1 | G-Switch | SMD,2.8x1.9mm |  | Tactile Switch SPST 180gf 0.65mm SMD (SMT) Tab 2.8mm x 1.9mm Surface Mount | yes | 10 | 10 | 10 | 0.0533 | 0.53 | https://www.lcsc.com/product-detail/C41398747.html
25 | C5345939 | HC-TYPE-C-24P-CP1.0-5A-L9.25-01 | HCTL | SMD |  | USB-C (USB TYPE-C) Receptacle Connector 24 Position Clamp Plate | yes | 5 | 1 | 1 | 0.2560 | 1.28 | https://www.lcsc.com/product-detail/C5345939.html
26 | C1591 | CL10B104KB8NNNC | Samsung Electro-Mechanics | 0603 |  | 100nF ±10% 50V Ceramic Capacitor X7R 0603 | yes | 100 | 100 | 100 | 0.0138 | 1.38 | https://www.lcsc.com/product-detail/C1591.html
27 | C7432770 | HGC0603R5226M100NTHJ | Chinocera | 0603 |  | 22uF ±20% 10V Ceramic Capacitor X5R 0603 | yes | 50 | 10 | 10 | 0.0530 | 2.65 | https://www.lcsc.com/product-detail/C7432770.html
28 | C2986064 | UMK325B7106KMQP | Taiyo Yuden | 1210 |  | 10uF ±10% 50V Ceramic Capacitor X7R 1210 | yes | 25 | 5 | 5 | 0.1212 | 3.03 | https://www.lcsc.com/product-detail/C2986064.html
29 | C54973934 | CRF0603Q103BN | SIE | 0603 |  | 10kΩ 100mW 50V ±25ppm/℃ ±0.1% 0603 Chip Resistor - Surface Mount RoHS | yes | 20 | 20 | 20 | 0.0192 | 0.38 | https://www.lcsc.com/product-detail/C54973934.html
30 | C5301790 | SMTSOM205BTR | YIYUAN | - |  | Board Spacers, Standoffs RoHS | yes | 10 | 5 | 5 | 0.0554 | 0.55 | https://www.lcsc.com/product-detail/C5301790.html
31 | C49326311 | 0603C0G221J500NT | AIDE CAPACITOR | 0603 |  | 220pF C0G ±5% 50V 0603 Ceramic Capacitors RoHS | yes | 100 | 100 | 100 | 0.0030 | 0.30 | https://www.lcsc.com/product-detail/C49326311.html
32 | C2930027 | FRC0603J103 TS | FOJAN | 0603 |  | 10kΩ ±5% 100mW 0603 Thick Film Resistor | - | 100 | 100 | 100 | 0.0012 | 0.12 | https://www.lcsc.com/product-detail/C2930027.html
33 | C14677 | RC0603JR-075K1L | YAGEO | 0603 |  | 100mW 5.1kΩ 75V Thick Film Resistor ±100ppm/℃ ±5% 0603 Chip Resistor - Surface Mount RoHS | yes | 100 | 100 | 100 | 0.0021 | 0.21 | https://www.lcsc.com/product-detail/C14677.html
34 | C844140 | CRCW06031M00FKEB | VISHAY | 0603 |  | 100mW 1MΩ Thick Film Resistor ±100ppm/℃ ±1% 0603 Chip Resistor - Surface Mount RoHS | yes | 20 | 20 | 20 | 0.0031 | 0.06 | https://www.lcsc.com/product-detail/C844140.html
35 | C112433 | WR06X1001FTL | Walsin | 0603 |  | 100mW 1kΩ 75V Thick Film Resistor ±100ppm/℃ ±1% 0603 Chip Resistor - Surface Mount RoHS | yes | 100 | 100 | 100 | 0.0018 | 0.18 | https://www.lcsc.com/product-detail/C112433.html
36 | C212300 | BAV199T-7-F | DIODES | SOT-523 |  | Diode Array 1 Pair Series Connection 85V 215mA Surface Mount SOT-523 | yes | 5 | 5 | 5 | 0.0835 | 0.42 | https://www.lcsc.com/product-detail/C212300.html
37 | C19666 | CL10A475KO8NNNC | Samsung Electro-Mechanics | 0603 |  | 4.7uF ±10% 16V Ceramic Capacitor X5R 0603 | yes | 10 | 10 | 10 | 0.0371 | 0.37 | https://www.lcsc.com/product-detail/C19666.html
38 | C54921059 | HRC0603J564 ENTN | HWA CHN | 0603 |  | 560kΩ 100mW 50V Thick Film Resistor ±5% ±100ppm/℃ 0603 Chip Resistor - Surface Mount RoHS | yes | 100 | 100 | 100 | 0.0010 | 0.10 | https://www.lcsc.com/product-detail/C54921059.html
39 | C376813 | TCC0603X7R153K500CT | CCTC | 0603 |  | 15nF ±10% 50V Ceramic Capacitor X7R 0603 | yes | 100 | 100 | 100 | 0.0070 | 0.70 | https://www.lcsc.com/product-detail/C376813.html
40 | C2907104 | FRC0603J153 TS | FOJAN | 0603 |  | 15kΩ ±5% 100mW 0603 Thick Film Resistor | yes | 100 | 100 | 100 | 0.0019 | 0.19 | https://www.lcsc.com/product-detail/C2907104.html
41 | C3833060 | GRM188R61E106MA73J | muRata | 0603 |  | 10uF ±20% 25V Ceramic Capacitor X5R 0603 | yes | 60 | 20 | 20 | 0.0390 | 2.34 | https://www.lcsc.com/product-detail/C3833060.html
42 | C49490376 | HCTC-160808-4R7-M | YOUCHI | 0603 |  | 1A 4.7uH ±20% 585mΩ 1.2A Molded Inductor 0603 Fixed Inductors RoHS | yes | 5 | 5 | 5 | 0.0859 | 0.43 | https://www.lcsc.com/product-detail/C49490376.html

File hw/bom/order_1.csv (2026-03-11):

LCSC Part Number | Manufacture Part Number | Manufacturer | Customer NO. | Package | Description | RoHS | Quantity | Unit Price(€) | Ext.Price(€) | Estimated lead time (business days) | Date Code / Lot No.
C473369 | TLV333IDBVR | TI |  | SOT-23-5 | 2uV Rail-to-Rail Input, Rail-to-Rail Output 70pA 0.16V/us 102dB 17uA 350kHz 1 SOT-23-5 Amplifiers RoHS | YES | 5 | 0.2121 | 1.06
C2827931 | SS24L | Guangdong Hottech |  | SOD-123FL | Diode Independent 40V 2A Surface Mount SOD-123FL | YES | 20 | 0.0214 | 0.43
C2931472 | U263-163N-4OS1735 | XKB Connection |  | SMD | USB-C (USB TYPE-C) Receptacle Connector 16 Position Surface Mount | YES | 5 | 0.2518 | 1.26
C2999960 | MM5Z3V3 | Slkor |  | SOD-523 | Zener Diode Independent 3.3V 200mW Surface Mount SOD-523 | YES | 20 | 0.0181 | 0.36
C52754543 | RB521S30T1G-HXY | HXY MOSFET |  | SOD-523 | 1A 1 Independent 30V 350mV@10mA 200mA SOD-523 Single Diodes RoHS | YES | 20 | 0.0212 | 0.42
C42442062 | CH32X035F8U6 | WCH |  | QFN-20-EP(3x3) | QFN-20-EP(3x3) Microcontrollers RoHS | YES | 5 | 0.446 | 2.23
C780769 | AP63203WU-7 | DIODES |  | TSOT-23-6 | 1.1MHz Buck Fixed 2A 3.3V 3.8V~32V TSOT-23-6 Voltage Regulators - DC DC Switching Regulators RoHS | YES | 5 | 0.3766 | 1.88
C7466527 | AGM403AP | AGMSEMI |  | PDFN3.3x3.3-8 | N-Channel 40V 65A 69W Surface Mount PDFN3.3x3.3 | YES | 5 | 0.2575 | 1.29
C2906999 | FRC0603F1803TS | FOJAN |  | 0603 | 180kΩ ±1% 100mW 0603 Thick Film Resistor | YES | 100 | 0.001 | 0.10
C4169844 | RS73F1JTTD2703B | KOA |  | 0603 | 200mW 270kΩ Thick Film Resistor ±25ppm/℃ ±0.1% 0603 Chip Resistor - Surface Mount RoHS | YES | 5 | 0.0638 | 0.32
C2932326 | MT3608L | XI'AN Aerosemi Tech |  | SOT-23-6 | 1.2MHz Boost Adjustable 2.2V~16V 2.5A SOT-23-6 Voltage Regulators - DC DC Switching Regulators RoHS | YES | 10 | 0.0373 | 0.37
C138714 | TPD4E05U06DQAR | TI |  | USON-10(1x2.5) | 14VC Clamp 2.5A@8/20us Ipp TVS DIODE USON-10(1x2.5) | YES | 5 | 0.0682 | 0.34
C19274408 | SC7A20HTR | Hangzhou Silan Microelectronics |  | LGA-12(2x2) | LGA-12(2x2) Accelerometers RoHS | YES | 5 | 0.2417 | 1.21
C52741377 | CPN201610H6R8MT | Magnetsyc |  | 0806 | 820mA 6.8uH 1.1A 545mΩ ±20% 0806 Fixed Inductors RoHS | YES | 20 | 0.0277 | 0.55
C110776 | RT0603BRD071KL | YAGEO |  | 0603 | 100mW 1kΩ 75V Thin Film Resistor ±25ppm/℃ ±0.1% 0603 Chip Resistor - Surface Mount RoHS | YES | 20 | 0.0187 | 0.37
C162670 | NCU18XH103F6SRB | muRata |  | 0603 | NTC Thermistor 10kΩ Surface Mount 0603 | YES | 10 | 0.0533 | 0.53
C46818248 | SIQ-02FVS3 | LZG |  | - | Encoders - Industrial RoHS | YES | 5 | 0.9816 | 4.91
C41414522 | NSG10752 | WXNSIC |  | SOT-23-6 | High Side Gate Driver IC MOSFET IGBT SOT-23-6 | YES | 5 | 0.4842 | 2.42
C76799 | MLZ1608M4R7WT000 | TDK |  | 0603 | 350mA 4.7uH 120mA 500mΩ Multilayer inductor ±20% 0603 Fixed Inductors RoHS | YES | 10 | 0.0351 | 0.35
C98192 | CL21A475KBQNNNE | Samsung Electro-Mechanics |  | 0805 | 4.7uF ±10% 50V Ceramic Capacitor X5R 0805 | YES | 10 | 0.0179 | 0.18
C29936 | CL10B105KA8NNNC | Samsung Electro-Mechanics |  | 0603 | 1uF ±10% 25V Ceramic Capacitor X7R 0603 | YES | 50 | 0.0056 | 0.28
C2997487 | MPD220M1VD19040R | Ymin |  | SMD,7.3x4.3mm | 35V 22uF 3.2A@100kHz 40mΩ@100kHz ±20% SMD,7.3x4.3mm Aluminum - Polymer Capacitors RoHS | YES | 5 | 0.7063 | 3.53
C5370906 | FC-ALX 4030D-2R2MT | FANGCHENG |  | SMD,4.2x4.2mm | 8.1A 2.2uH 8.1A 10.7mΩ Molded Inductor ±20% SMD,4.2x4.2mm Fixed Inductors RoHS | YES | 5 | 0.4781 | 2.39
C18723014 | X069-9616TSWIG02-H14 | Wisevision |  | - | 0.69 96x16 SSD1312 chip I2C LCD, OLED, Graphic RoHS | YES | 2 | 1.3337 | 2.67
C386166 | UMK325AB7106KMHP | Taiyo Yuden |  | 1210 | 10uF ±10% 50V Ceramic Capacitor X7R 1210 AEC-Q200 | YES | 25 | 0.0854 | 2.14
C38582720 | TPA191A4-SC6R | 3PEAK |  | SOT-363 | 50uV -300mV~+36V 22uA 2.5V/us 120dB 30kHz 80uA 100V/V SOT-363 Amplifiers RoHS | YES | 5 | 0.53 | 2.65
C5185587 | CUM1206-15FR004 | FORT |  | 1206 | 1W 4mΩ SMD ±50ppm/℃ Current Sense Resistor ±1% 1206 Current Sense Resistors RoHS | YES | 5 | 0.0522 | 0.26

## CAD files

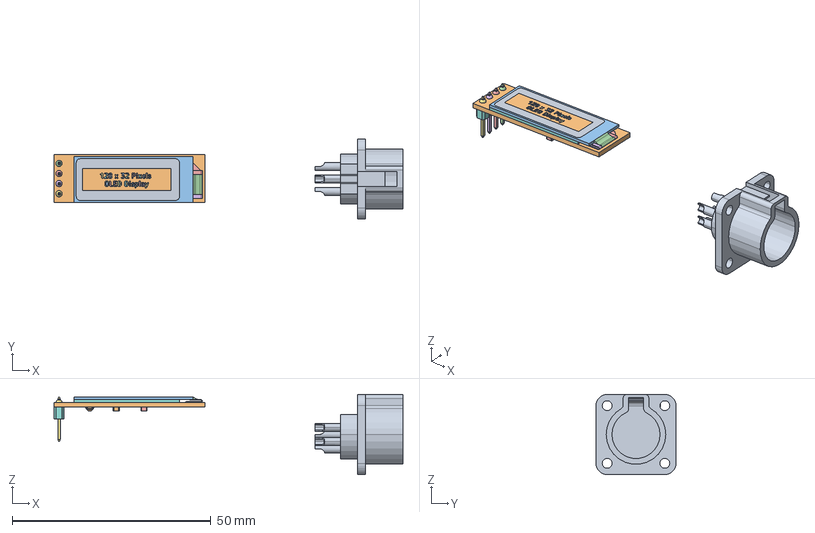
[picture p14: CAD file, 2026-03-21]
3D/extenal-handle/External-Handle-Assembly.FCStd
87.9 x 20.2 x 20.2 mm
RPC1-12RB-6P001
Board_001
Board_002
Board_003
Board_004
Board_005
Board_006
Board_007
Board_008
Board_009
Board_010
Board_011
Board_012
Board_013
Board_014
Board_015
Board_016
Board_017
Board_018
Board_019
Board_020
Board_021
Board_022
Board_023
Board_024
Board_025
Board_026
Board_027
Board_028
Board_029
Board_030
Board_031
Board_032
Board_033
Board_034
Board_035
Board_036
Board_037
Board_038
Board_039
Board_040
Board_041
Board_042
1x4 Male Header_001
1x4 Male Header_002
1x4 Male Header_003
1x4 Male Header_004
1x4 Male Header_005
0603 Capacitor_001
0603 Capacitor_002
0603 Capacitor_003
0603 Capacitor_005
0603 Capacitor_006
0603 Capacitor_007
0603 Capacitor_009
0603 Capacitor_010
0603 Capacitor_011
0603 Capacitor_013
0603 Capacitor_014
0603 Capacitor_015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

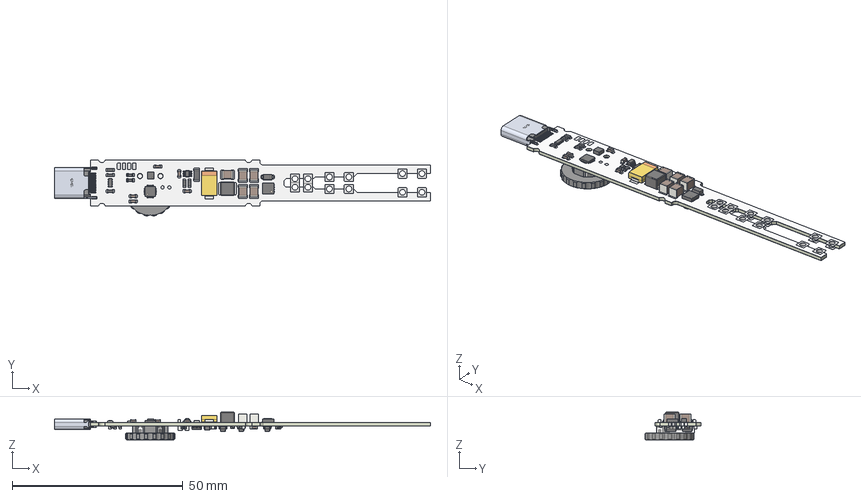
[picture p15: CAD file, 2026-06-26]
hw/main_board.step
110.2 x 16.4 x 8.08 mm
C_1210_3225Metric x 5
SOT-363_SC-70-6
C_0603_1608Metric x 20
UQFN-20-1EP_3x3mm_Pitch0.4mm
R_0603_1608Metric x 16
USB-SMD_HC-TYPE-C-24P-CP1.0-5A-L10.45-01
LGA_12_2x2mm_P05mm
VSON_8_33x33mm_Pitch065mm_NexFET
USON_10_25x10mm_Pitch05mm
D_SOD_123F
L_Changjiang_FNR4030S
CP_EIA_7343_20_Kemet_V
R_1206_3216Metric
SOT-23-6 x 2
L_0603_1608Metric
TSOT-23-6
C_0805_2012Metric x 2
SW_SMD_2.8x1.9mm
D_SOD_523 x 2
SOT-23-5
L_Changjiang_FTC201612S
69E606F8-E654-4B8A-A1E6-D8F60CE14AFD
usbc_soldering_iron_pad
usbc_soldering_iron_soldermask x 2
usbc_soldering_iron_PCB

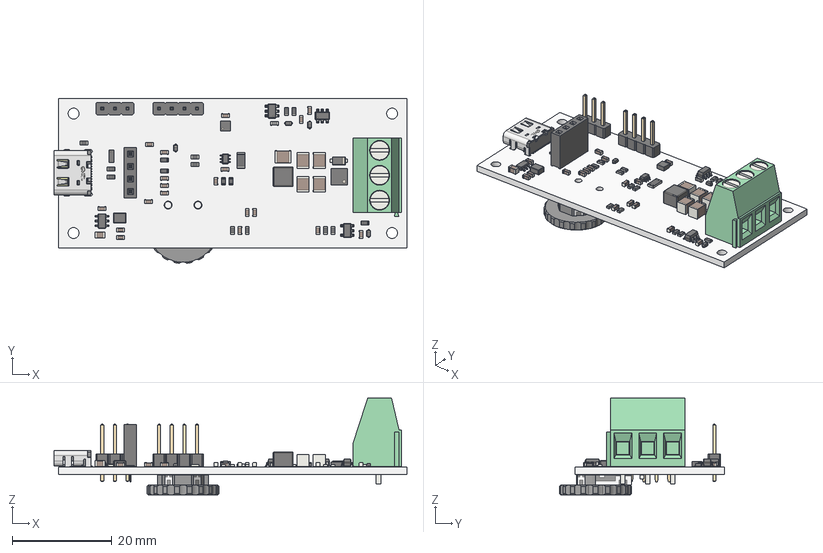
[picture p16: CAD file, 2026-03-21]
3D/extenal-handle/main_pcb.step
70.9 x 33.1 x 19.5 mm
C_0603_1608Metric x 20
PinHeader_1x03_P2.54mm_Vertical
C_1210_3225Metric x 5
L_0603_1608Metric
USON-10_2.5x1.0mm_P0.5mm
VSON-8_3.3x3.3mm_P0.65mm_NexFET
D_SOD-523 x 4
R_0603_1608Metric x 17
L_Changjiang_FTC252012S
SOT-23-5
USB-C-SMD_U263-163N-4GS1735
SOT-23-6 x 2
D_SOD-123F
SOT-363_SC-70-6
LGA-12_2x2mm_P0.5mm
PinHeader_1x04_P2.54mm_Vertical
L_Changjiang_FNR4030S
TSOT-23-6
C_0805_2012Metric
TerminalBlock_Phoenix_MKDS-1,5-3_1x03_P5.00mm_Horizontal
R_1206_3216Metric
PinSocket_1x04_P2.54mm_Vertical
SIQ-02FVS3
usbc_soldering_iron_PCB

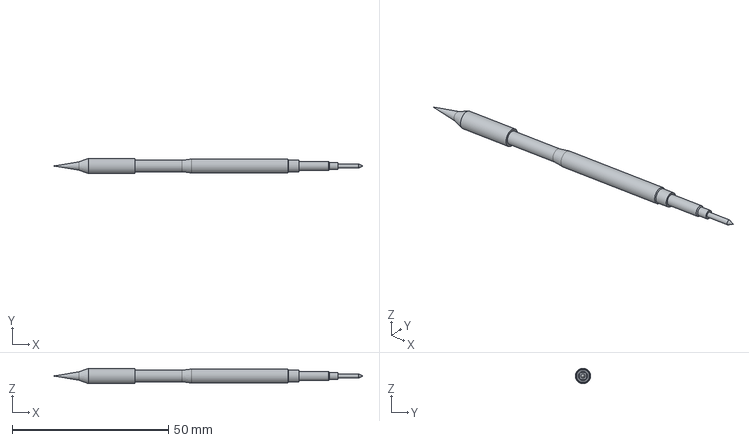
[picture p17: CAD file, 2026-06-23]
3D/c245-903-Tip.step
99.0 x 4.90 x 4.90 mm

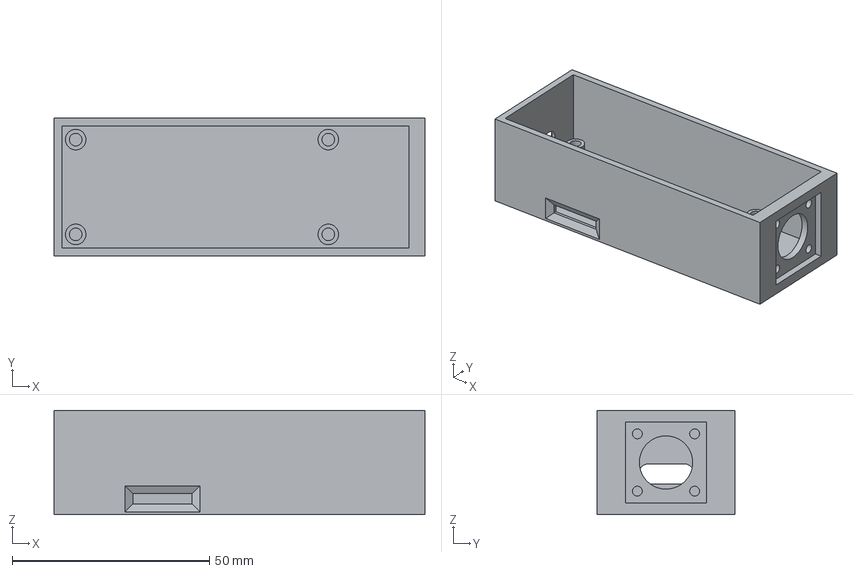
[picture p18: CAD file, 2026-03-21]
3D/extenal-handle/export/Enclosure-Shell.step
94.0 x 35.0 x 26.4 mm

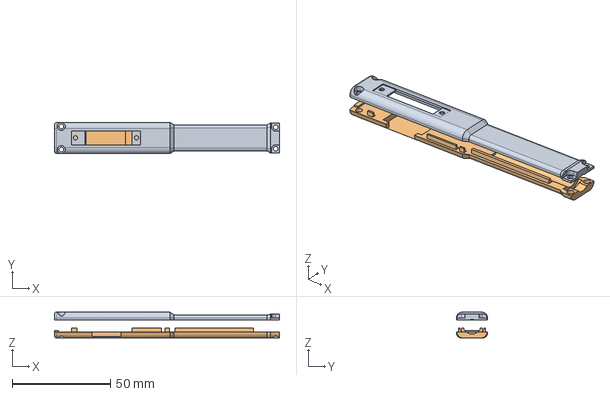
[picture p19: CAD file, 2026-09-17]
3D/stylo/Housing_V3.FCStd
114.3 x 15.9 x 13.1 mm
Top
Bottom

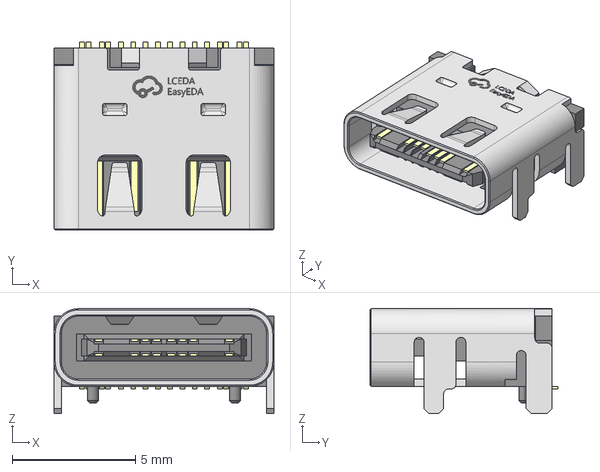
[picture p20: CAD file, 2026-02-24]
hw/oled_pcb/footprints/USB-C-SMD_U263-163N-4GS1735.step
8.94 x 7.65 x 4.27 mm

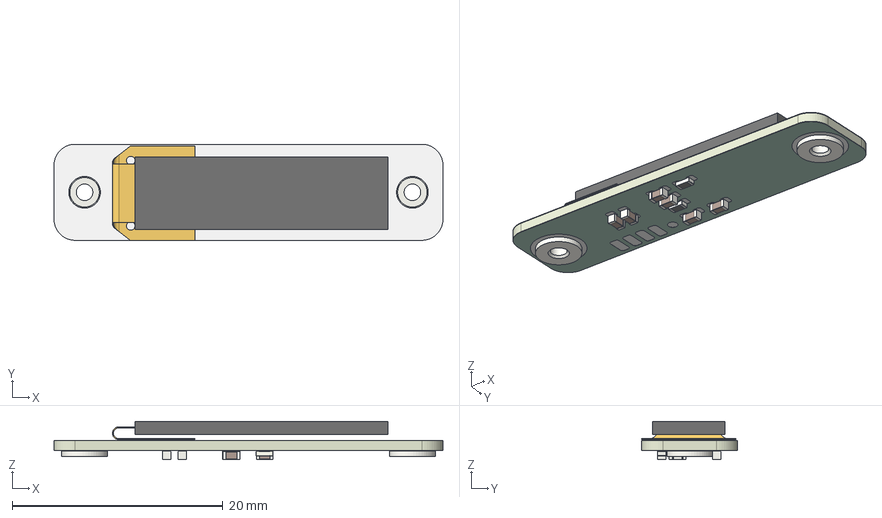
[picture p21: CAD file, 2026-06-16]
hw/oled_pcb/oled_board.step
36.9 x 9.14 x 3.63 mm
Screen
Cable
C_0603_1608Metric x 6
R_0603_1608Metric x 2
Mounting_Wuerth_WA-SMSI-M2_H0.5mm_9774005243 x 2
oled_board_pad
oled_board_soldermask x 2
oled_board_PCB

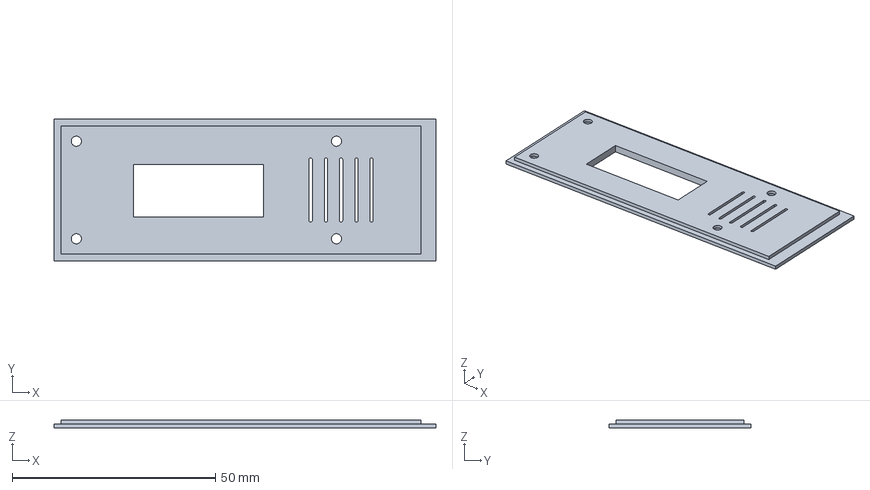
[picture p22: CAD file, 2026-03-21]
3D/extenal-handle/Enclosure.FCStd
94.0 x 35.0 x 2.00 mm

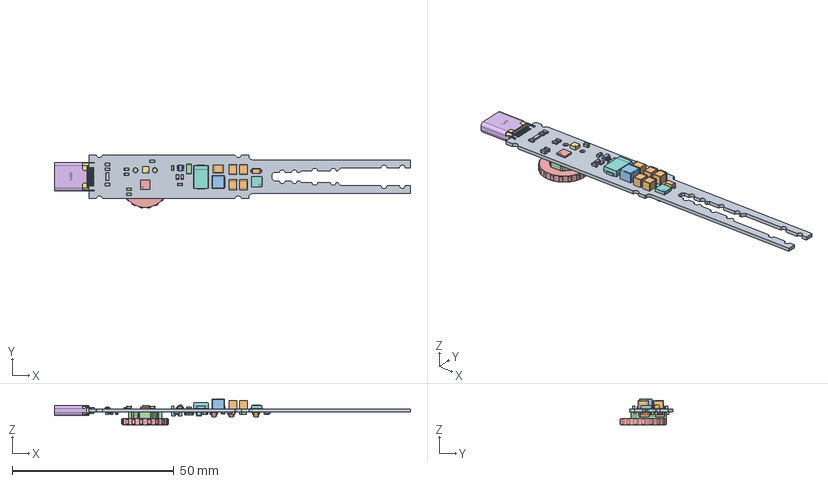
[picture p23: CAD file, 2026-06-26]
3D/stylo/board.FCStd
110.2 x 16.4 x 8.00 mm
Pcb_add
C24_C_1210_3225Metric_29a8166602b001 x 5
U10_SOT-363_SC-70-6_26458084a60f001
C3_C_0603_1608Metric_9232a6cde906 x 20
U2_UQFN-20-1EP_3x3mm_Pitch0.4mm_36e3e03a4a23
R19_R_0603_1608Metric_7cb37decb3fd001 x 16
U1_LGA_12_2x2mm_P05mm_eb548277b26e001
Q1_VSON_8_33x33mm_Pitch065mm_NexFET_d8f967ad0826
U3_USON_10_25x10mm_Pitch05mm_6513b2393d001
D5_D_SOD_123F_7925ebff5843
L2_L_Changjiang_FNR4030S_1aed558f1abc001
R11_R_1206_3216Metric_6e50619bf4f001
U9_SOT-23-6_2df3dcf13f001 x 2
L3_L_0603_1608Metric_20b768465bbc001
U5_TSOT-23-6_34e7e2ecf651
C5_C_0805_2012Metric_9774fafa466b001 x 2
D4_D_SOD_523_7509c8927e001 x 2
U6_SOT-23-5_dc119dbc7921
L1_L_Changjiang_FTC201612S_090bb8f11c001
69E606F8-E654-4B8A-A1E6-D8F60CE14AFD002
69E606F8-E654-4B8A-A1E6-D8F60CE14AFD003
USB-SMD_HC-TYPE-C-24P-CP1.0-5A-L10.45-01
USB-SMD_HC-TYPE-C-24P-CP1.0-5A-L10.45-001
C13_CP_EIA_7343_20_Kemet_V_19b0cd14a8dc
SW1_SW_SMD_2.8x1.9mm_2db771562312

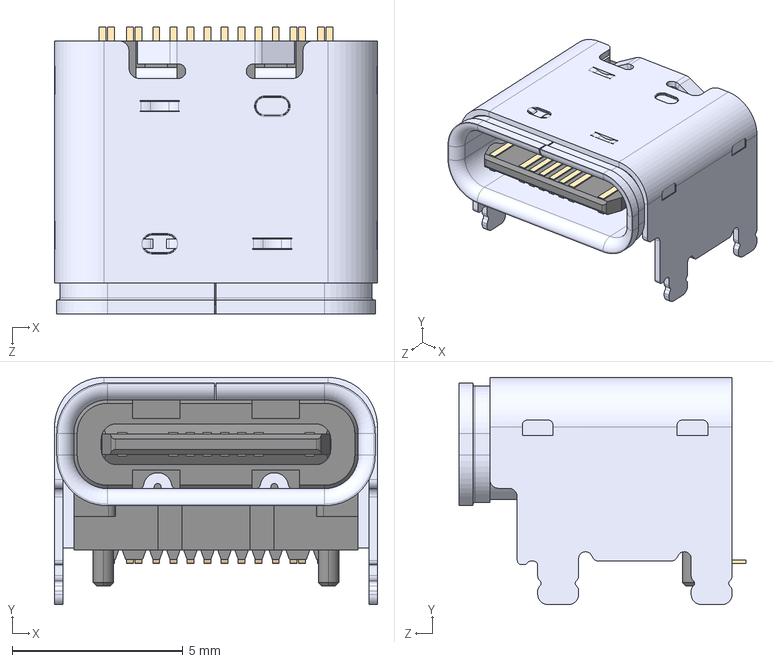
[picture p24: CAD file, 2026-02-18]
hw/oled_pcb/footprints/GT-USB-7016D.step
9.47 x 6.66 x 8.40 mm

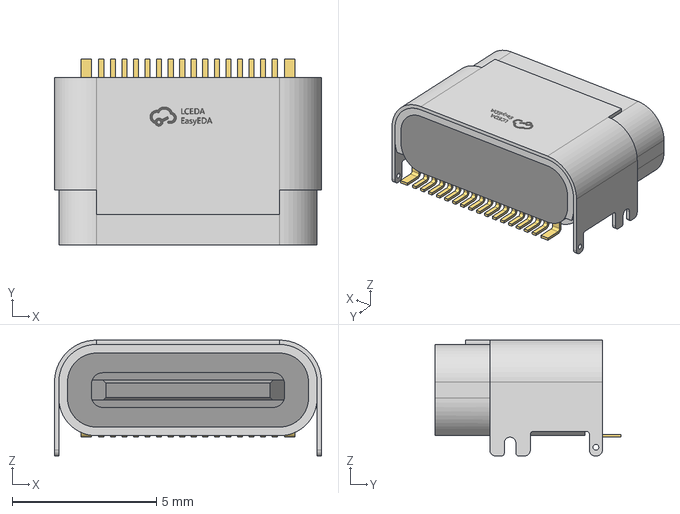
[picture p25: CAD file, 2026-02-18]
hw/oled_pcb/footprints/GT-USB-7025.step
9.24 x 6.45 x 4.01 mm
TYPE-C-SMD_GT-USB-7025~TYPE-C-SMD_GT-USB-7025~uTaK003 x 3

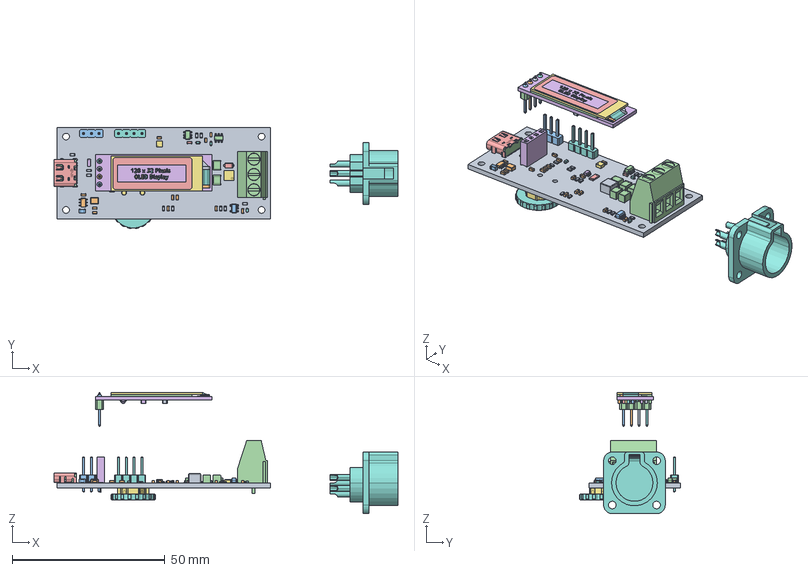
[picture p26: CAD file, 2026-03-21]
3D/extenal-handle/usbc_soldering_iron.FCStd
112.6 x 33.1 x 39.8 mm
Pcb_add
C12_C_0603_1608Metric_f94a0cd6ba84 x 20
J4_PinHeader_1x03_P254mm_Vertical_a86946922fa0
C21_C_1210_3225Metric_a35681aad3bc x 5
L3_L_0603_1608Metric_9f11ed3cb953
U3_USON_10_25x10mm_Pitch05mm_1400341fed81
Q1_VSON_8_33x33mm_Pitch065mm_NexFET_9213364df752
D2_D_SOD_523_24b27e9743b1 x 4
R9_R_0603_1608Metric_0e75d0b7dc58 x 17
L1_L_Changjiang_FTC252012S_48ad00a3afb0
U6_SOT-23-5_71eb4928897a
U9_SOT-23-6_7506a14c86f2 x 2
D5_D_SOD_123F_2b6a059ba69a
U10_SOT-363_SC-70-6_924a9fc27b2e
U1_LGA_12_2x2mm_P05mm_3c594d2faddb
J2_PinHeader_1x04_P254mm_Vertical_47e2c700f232
L2_L_Changjiang_FNR4030S_2548736b7249
U5_TSOT-23-6_53f963aaf5bf
C5_C_0805_2012Metric_e90b69a0600b
J16_TerminalBlock_Phoenix_MKDS_15_3_1x03_P500mm_Horizontal_6c90c5e94b96
R11_R_1206_3216Metric_4f2469612a62
J5_PinSocket_1x04_P2.54mm_Vertical_fe351d1c2c82
69E606F8-E654-4B8A-A1E6-D8F60CE14AFD
69E606F8-E654-4B8A-A1E6-D8F60CE14AFD001
USB-C-SMD_U263-163N-4GS1735~TYPE-C-SMD_U263-163N-4GS1735~lxTM
USB-C-SMD_U263-163N-4GS1735~TYPE-C-SMD_U263-163N-4GS1735~lxTM001
USB-C-SMD_U263-163N-4GS1735~TYPE-C-SMD_U263-163N-4GS1735~lxTM002
USB-C-SMD_U263-163N-4GS1735~TYPE-C-SMD_U263-163N-4GS1735~lxTM003
USB-C-SMD_U263-163N-4GS1735~TYPE-C-SMD_U263-163N-4GS1735~lxTM004
USB-C-SMD_U263-163N-4GS1735~TYPE-C-SMD_U263-163N-4GS1735~lxTM005
USB-C-SMD_U263-163N-4GS1735~TYPE-C-SMD_U263-163N-4GS1735~lxTM006
USB-C-SMD_U263-163N-4GS1735~TYPE-C-SMD_U263-163N-4GS1735~lxTM007
USB-C-SMD_U263-163N-4GS1735~TYPE-C-SMD_U263-163N-4GS1735~lxTM008
USB-C-SMD_U263-163N-4GS1735~TYPE-C-SMD_U263-163N-4GS1735~lxTM009
USB-C-SMD_U263-163N-4GS1735~TYPE-C-SMD_U263-163N-4GS1735~lxTM010
USB-C-SMD_U263-163N-4GS1735~TYPE-C-SMD_U263-163N-4GS1735~lxTM011
USB-C-SMD_U263-163N-4GS1735~TYPE-C-SMD_U263-163N-4GS1735~lxTM012
USB-C-SMD_U263-163N-4GS1735~TYPE-C-SMD_U263-163N-4GS1735~lxTM013
USB-C-SMD_U263-163N-4GS1735~TYPE-C-SMD_U263-163N-4GS1735~lxTM014
USB-C-SMD_U263-163N-4GS1735~TYPE-C-SMD_U263-163N-4GS1735~lxTM015
USB-C-SMD_U263-163N-4GS1735~TYPE-C-SMD_U263-163N-4GS1735~lxTM016
USB-C-SMD_U263-163N-4GS1735~TYPE-C-SMD_U263-163N-4GS1735~lxTM017
USB-C-SMD_U263-163N-4GS1735~TYPE-C-SMD_U263-163N-4GS1735~lxTM018
USB-C-SMD_U263-163N-4GS1735~TYPE-C-SMD_U263-163N-4GS1735~lxTM019
USB-C-SMD_U263-163N-4GS1735~TYPE-C-SMD_U263-163N-4GS1735~lxTM020
USB-C-SMD_U263-163N-4GS1735~TYPE-C-SMD_U263-163N-4GS1735~lxTM021
USB-C-SMD_U263-163N-4GS1735~TYPE-C-SMD_U263-163N-4GS1735~lxTM022
USB-C-SMD_U263-163N-4GS1735~TYPE-C-SMD_U263-163N-4GS1735~lxTM023
USB-C-SMD_U263-163N-4GS1735~TYPE-C-SMD_U263-163N-4GS1735~lxTM024
USB-C-SMD_U263-163N-4GS1735~TYPE-C-SMD_U263-163N-4GS1735~lxTM025
USB-C-SMD_U263-163N-4GS1735~TYPE-C-SMD_U263-163N-4GS1735~lxTM026
USB-C-SMD_U263-163N-4GS1735~TYPE-C-SMD_U263-163N-4GS1735~lxTM027
USB-C-SMD_U263-163N-4GS1735~TYPE-C-SMD_U263-163N-4GS1735~lxTM028
Board_001
Board_002
Board_003
Board_004
Board_005
Board_006
Board_007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

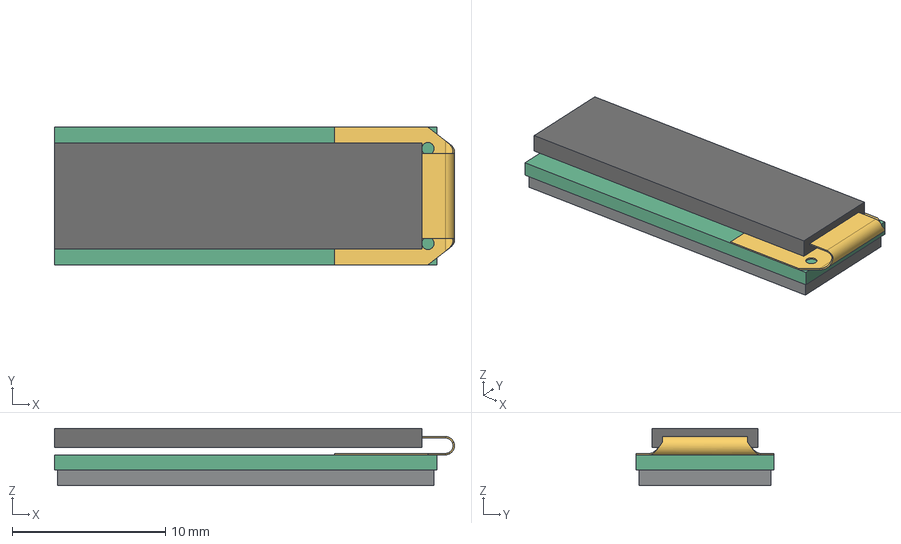
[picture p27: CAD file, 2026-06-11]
3D/stylo/OLED_0.69_X069-9616TSWIG02-H14_PCB.step
26.1 x 9.00 x 3.73 mm
Screen
Cable
PCB
Components

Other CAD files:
3D/c245-903.FCStd
3D/extenal-handle/export/Enclosure-Cap.step
3D/extenal-handle/RPC1-12RB-6P.step
3D/stylo/OLED_0.69_X069-9616TSWIG02-H14.FCStd
3D/extenal-handle/I2C_OLED.step
3D/stylo/Housing_V2.FCStd
3D/stylo/OLED_0.69_X069-9616TSWIG02-H14_PCB.FCStd

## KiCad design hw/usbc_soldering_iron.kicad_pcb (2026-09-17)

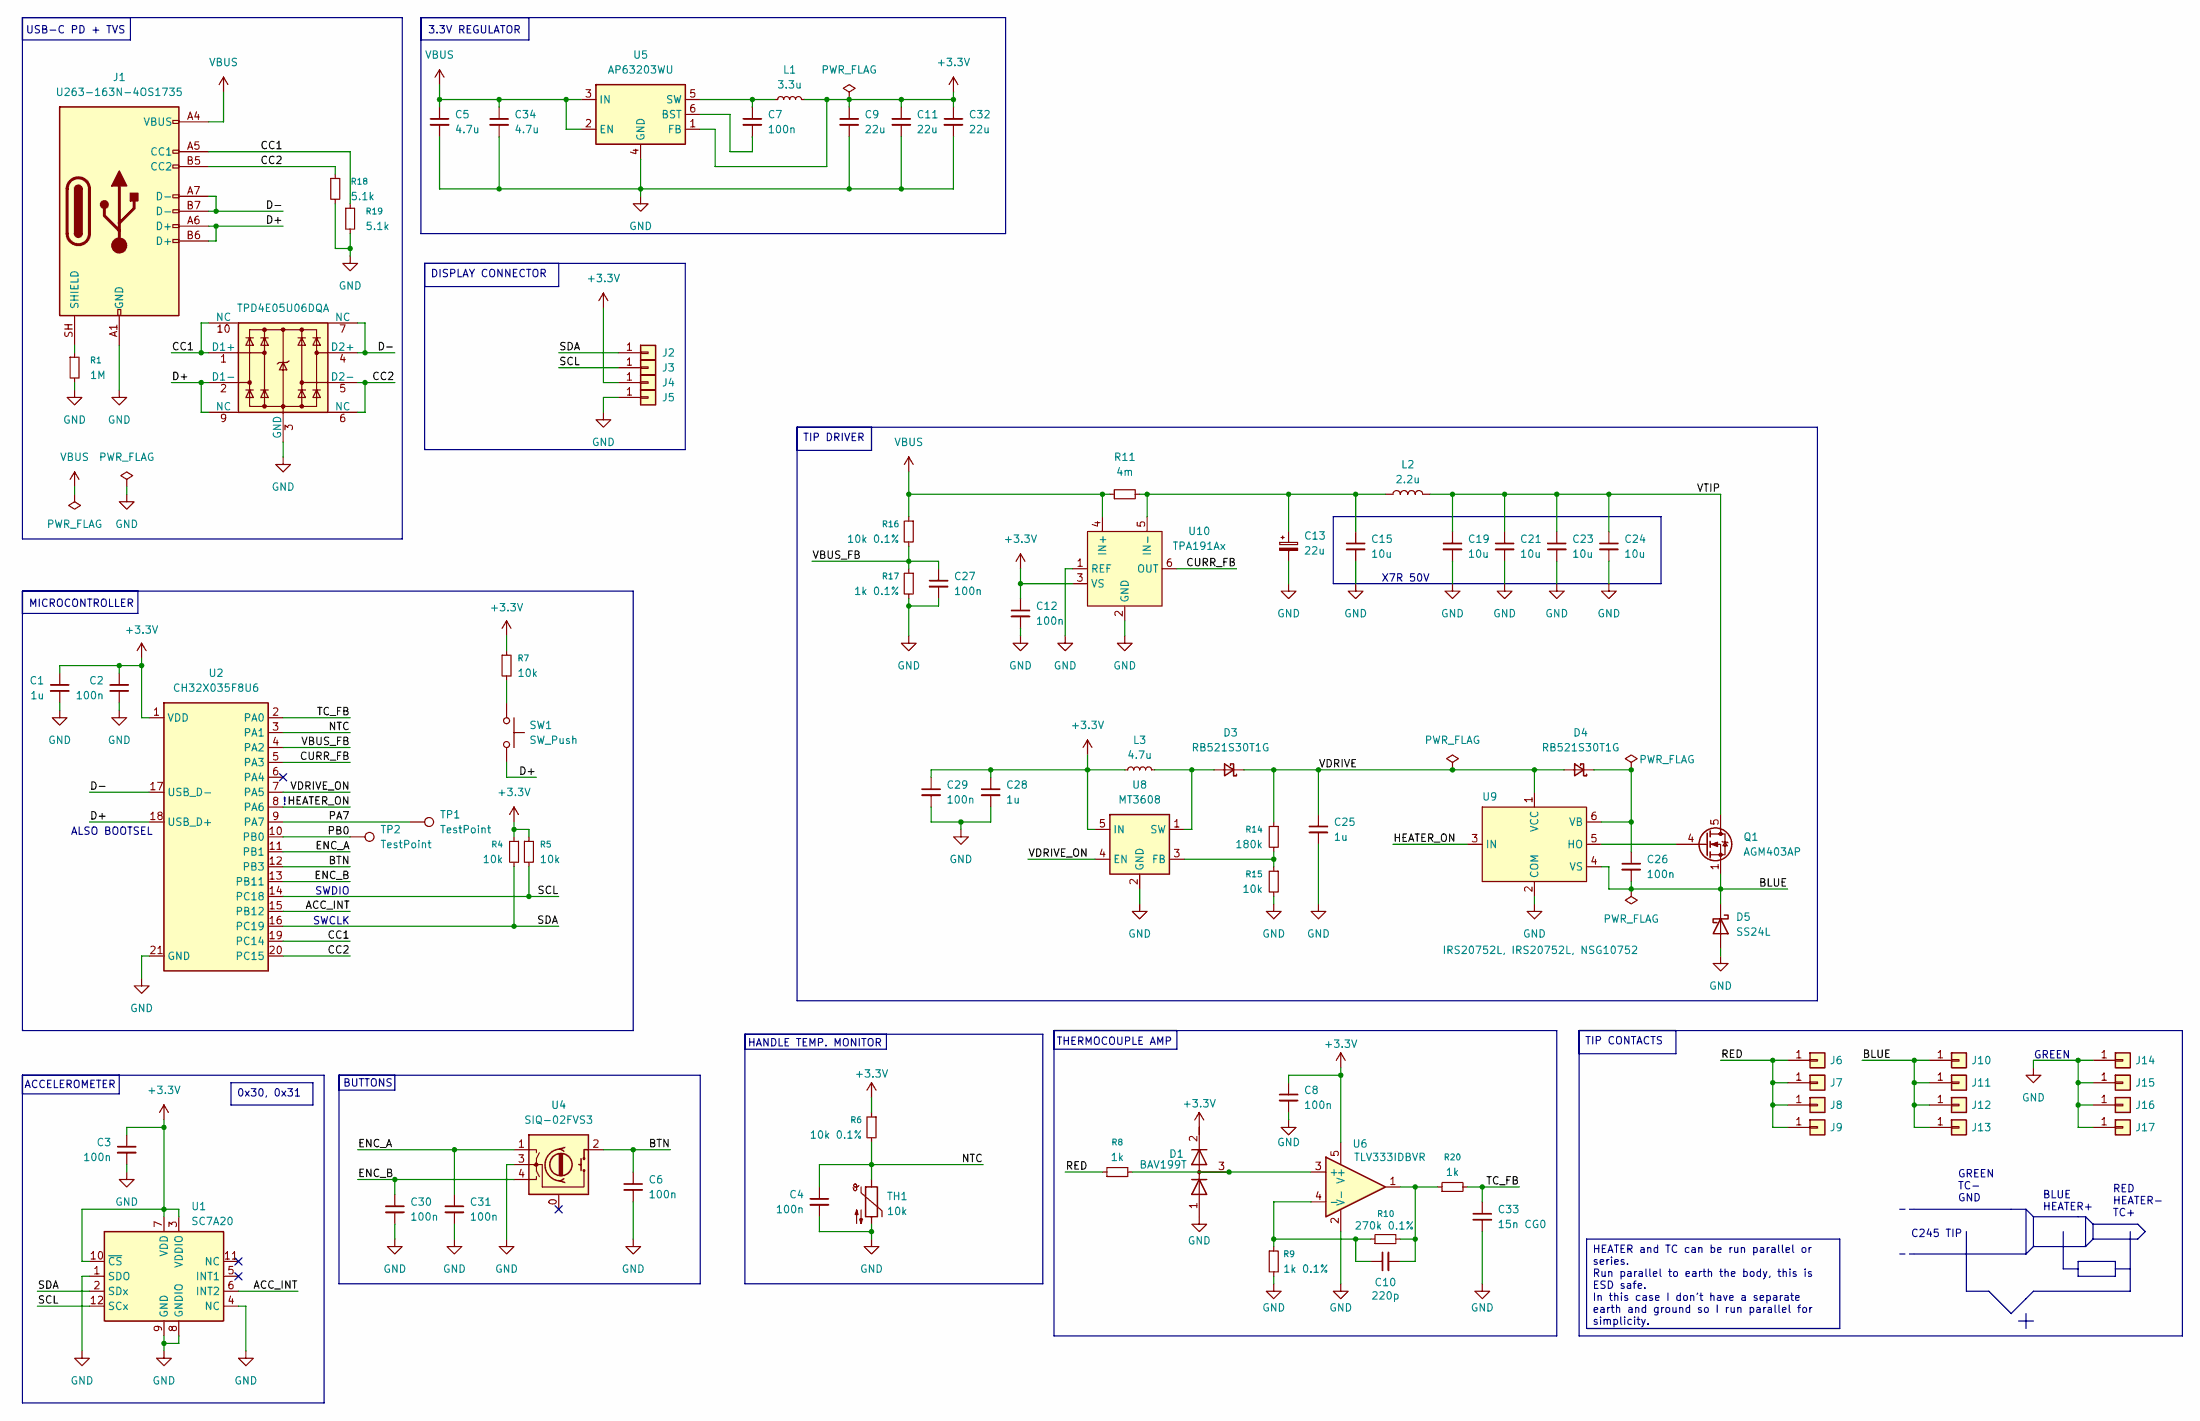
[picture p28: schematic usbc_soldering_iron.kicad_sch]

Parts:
C1, C25, C28: 1u; C_0603_1608Metric
C2, C3, C4, C6, C7, C8, C12, C26, C27, C29, C30, C31: 100n; C_0603_1608Metric
C5, C34: 4.7u; C_0805_2012Metric
C9, C11, C32: 22u; C_0603_1608Metric
C10: 220p; C_0603_1608Metric
C13: 22u; CP-SMD_L7.3-W4.3-FD
C15, C19, C21, C23, C24: 10u; C_1210_3225Metric
C33: 15n CG0; C_0603_1608Metric
D1: BAV199T; SOT-523
D3, D4: RB521S30T1G; D_SOD-523
D5: SS24L; D_SOD-123F
J1: U263-163N-4OS1735; USB-SMD_HC-TYPE-C-24P-CP1.0-5A-L10.45-01
J2, J3, J4, J5: Conn_01x01; SolderWirePad_1x01_SMD_1x2mm
J6, J7, J8, J9, J10, J11, J12, J13, J14, J15, J16, J17: Conn_01x01; SolderWire-1sqmm_1x01_D1.4mm_OD2.7mm
L1: 3.3u; L_Changjiang_FTC201612S_Handsolder
L2: 2.2u; L_Changjiang_FNR4030S_Handsolder
L3: 4.7u; L_0603_1608Metric
Q1: AGM403AP; VSON-8_3.3x3.3mm_P0.65mm_NexFET
R1: 1M; R_0603_1608Metric
R4, R5, R7, R15: 10k; R_0603_1608Metric
R6, R16: 10k 0.1%; R_0603_1608Metric
R8, R20: 1k; R_0603_1608Metric
R9, R17: 1k 0.1%; R_0603_1608Metric
R10: 270k 0.1%; R_0603_1608Metric
R11: 4m; R_1206_3216Metric
R14: 180k; R_0603_1608Metric
R18, R19: 5.1k; R_0603_1608Metric
SW1: SW_Push; SW_PUSH_GT-TS201A-H0065
TH1: 10k; R_0603_1608Metric
TP1, TP2: TestPoint; TestPoint_Pad_D1.0mm
U1: SC7A20; LGA-12_2x2mm_P0.5mm
U2: CH32X035F8U6; QFN-20-1EP_3x3mm_P0.4mm_EP1.65x1.65mm; LCSC C42442062
U3: TPD4E05U06DQA; USON-10_2.5x1.0mm_P0.5mm
U4: SIQ-02FVS3; SIQ-02FVS3_Rotary_Encoder
U5: AP63203WU; TSOT-23-6
U6: TLV333IDBVR; SOT-23-5
U8: MT3608; SOT-23-6
U9: IRS20752L, IRS20752L, NSG10752; SOT-23-6
U10: TPA191Ax; SOT-363_SC-70-6

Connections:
+3.3V: C1.1, C2.1, C3.1, C8.1, C9.1, C11.1, C12.1, C28.1, C29.1, C32.1, D1.2 (K), J4.1 (Pin_1_1), L1.2, L3.1, R4.1, R5.1, R6.1, R7.1, U1.3 (VDDIO), U1.7 (VDD), U1.10 (~CS), U2.1 (VDD), U5.1 (FB), U6.5 (V+), U8.5 (IN), U10.3 (VS)
/ACC_INT: U1.6 (INT2), U2.15 (PB12)
/BLUE: C26.2, D5.1 (K), J10.1 (Pin_1_1), J11.1 (Pin_1_1), J12.1 (Pin_1_1), J13.1 (Pin_1_1), Q1.1 (S), Q1.2 (S), Q1.3 (S), U9.4 (VS)
/BTN: C6.1, U2.12 (PB3), U4.2
/CC1: J1.A5 (CC1), R19.1, U2.19 (PC14), U3.1 (D1+), U3.10 (NC)
/CC2: J1.B5 (CC2), R18.1, U2.20 (PC15), U3.5 (D2-), U3.6 (NC)
/CURR_FB: U2.5 (PA3), U10.6 (OUT)
/D+: J1.A6 (D+), J1.B6 (D+), SW1.2, U2.18 (USB_D+), U3.2 (D1-), U3.9 (NC)
/D-: J1.A7 (D-), J1.B7 (D-), U2.17 (USB_D-), U3.4 (D2+), U3.7 (NC)
/ENC_A: C31.1, U2.11 (PB1), U4.1
/ENC_B: C30.1, U2.13 (PB11), U4.4
/HEATER_ON: U2.8 (PA6), U9.3 (IN)
/NTC: C4.1, R6.2, TH1.1, U2.3 (PA1)
/PA7: TP1.1 (1_1), U2.9 (PA7)
/PB0: TP2.1 (1_1), U2.10 (PB0)
/RED: J6.1 (Pin_1_1), J7.1 (Pin_1_1), J8.1 (Pin_1_1), J9.1 (Pin_1_1), R8.1
/SCL: J3.1 (Pin_1_1), R5.2, U1.12 (SCx), U2.14 (PC18)
/SDA: J2.1 (Pin_1_1), R4.2, U1.2 (SDx), U2.16 (PC19)
/TC_FB: C33.1, R20.2, U2.2 (PA0)
/VBUS_FB: C27.1, R16.2, R17.1, U2.4 (PA2)
/VDRIVE: C25.1, D3.1 (K), D4.2 (A), R14.1, U9.1 (VCC)
/VDRIVE_ON: U2.7 (PA5), U8.4 (EN)
/VTIP: C19.1, C21.1, C23.1, C24.1, L2.2, Q1.5 (D)
GND: C1.2, C2.2, C3.2, C4.2, C5.2, C6.2, C8.2, C9.2, C11.2, C12.2, C13.2, C15.2, C19.2, C21.2, C23.2, C24.2, C25.2, C27.2, C28.2, C29.2, C30.2, C31.2, C32.2, C33.2, C34.2, D1.1 (A), D5.2 (A), J1.A1 (GND), J1.A12 (GND), J1.B1 (GND), J1.B12 (GND), J5.1 (Pin_1_1), J14.1 (Pin_1_1), J15.1 (Pin_1_1), J16.1 (Pin_1_1), J17.1 (Pin_1_1), R1.2, R9.2, R15.2, R17.2, R18.2, R19.2, TH1.2, U1.1 (SDO), U1.4 (NC), U1.8 (GNDIO), U1.9 (GND), U2.21 (GND), U3.3 (GND), U3.8 (GND), U4.3, U5.4 (GND), U6.2 (V-), U8.2 (GND), U9.2 (COM), U10.1 (REF), U10.2 (GND)
unnamed: C10.2, R10.2, R20.1, U6.1
unnamed: D1.3 (common), R8.2, U6.3 (+)
unnamed: D3.2 (A), L3.2, U8.1 (SW)
unnamed: C26.1, D4.1 (K), U9.6 (VB)
unnamed: J1.SH (SHIELD), R1.1
unnamed: Q1.4 (G), U9.5 (HO)
unnamed: R7.2, SW1.1
unnamed: C7.2, U5.6 (BST)
unnamed: C7.1, L1.1, U5.5 (SW)
unnamed: C10.1, R9.1, R10.1, U6.4 (-)
unnamed: R14.2, R15.1, U8.3 (FB)
unnamed: C13.1, C15.1, L2.1, R11.2, U10.5 (IN-)
VBUS: C5.1, C34.1, J1.A4 (VBUS), J1.A9 (VBUS), J1.B4 (VBUS), J1.B9 (VBUS), R11.1, R16.1, U5.2 (EN), U5.3 (IN), U10.4 (IN+)

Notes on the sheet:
SWCLK
RED HEATER- TC+
3.3V REGULATOR
SWDIO
ALSO BOOTSEL
USB-C PD + TVS
BUTTONS
ACCELEROMETER
BLUE HEATER+
HANDLE TEMP. MONITOR
GREEN
X7R 50V
THERMOCOUPLE AMP
MICROCONTROLLER
C245 TIP
GREEN TC- GND
TIP DRIVER
0x30, 0x31
DISPLAY CONNECTOR
HEATER and TC can be run parallel or series. Run parallel to earth the body, this is ESD safe. In this case I don't have a separate earth and ground so I run parallel for simplicity.
TIP CONTACTS

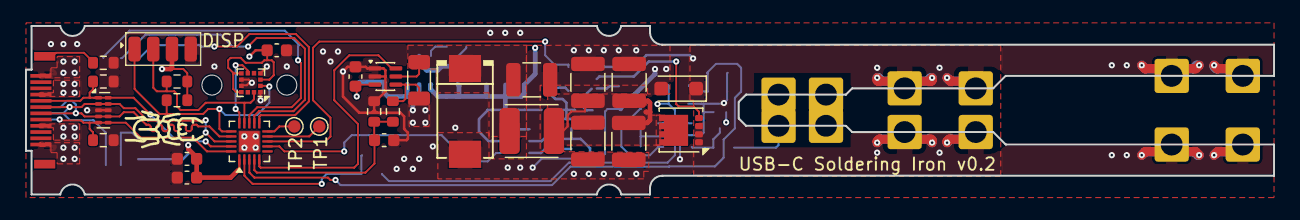
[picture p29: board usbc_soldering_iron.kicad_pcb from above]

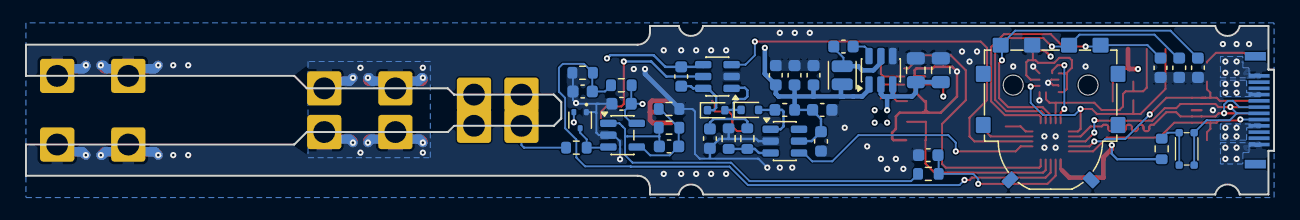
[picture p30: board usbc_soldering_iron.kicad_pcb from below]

Board: 4 copper layers, 100.0 x 13.5 mm, 82 parts (37 on the bottom side), 37 nets.

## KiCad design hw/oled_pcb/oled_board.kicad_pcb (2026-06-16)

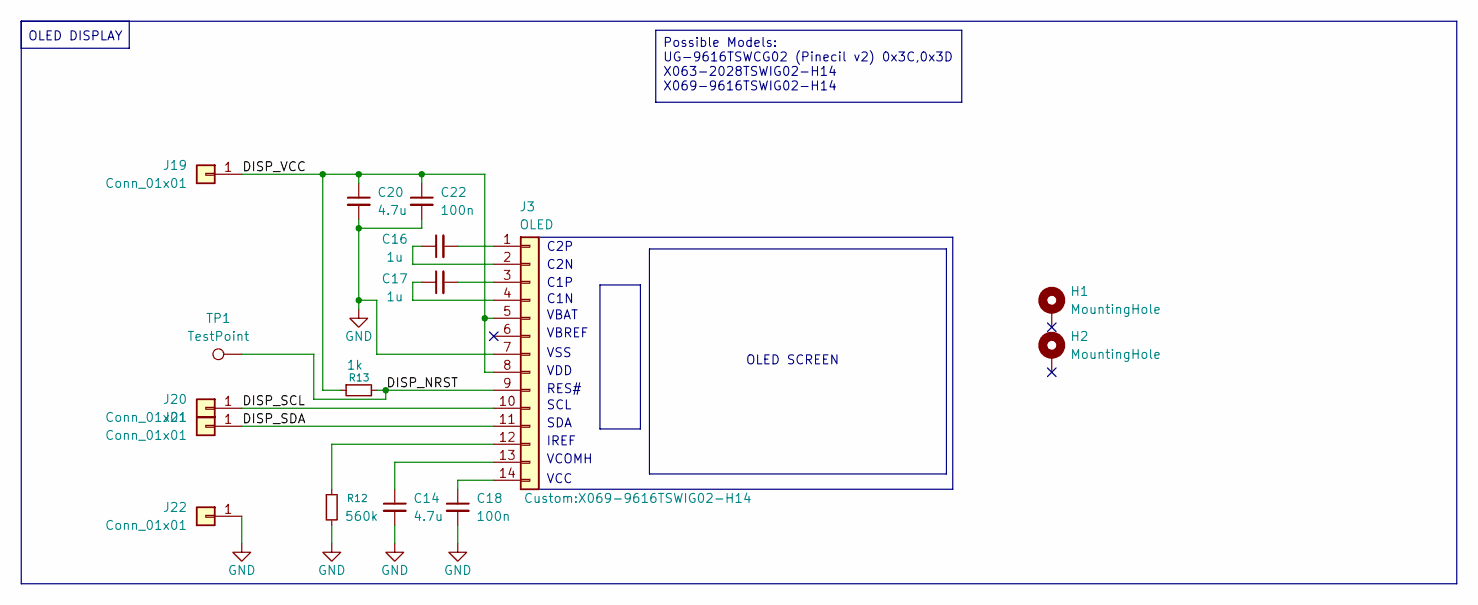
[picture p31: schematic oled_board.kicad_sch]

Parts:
C14, C20: 4.7u; C_0603_1608Metric
C16, C17: 1u; C_0603_1608Metric
C18, C22: 100n; C_0603_1608Metric
H1, H2: MountingHole; Mounting_Wuerth_WA-SMSI-M2_H0.5mm_9774005243
J3: OLED; X069-9616TSWIG02-H14
J19, J20, J21, J22: Conn_01x01; SolderWirePad_1x01_SMD_1x2mm
R12: 560k; R_0603_1608Metric
R13: 1k; R_0603_1608Metric
TP1: TestPoint; TestPoint_Pad_D1.0mm

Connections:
/DISP_NRST: J3.9, R13.2, TP1.1 (1_1)
/DISP_SCL: J3.10, J20.1 (Pin_1_1)
/DISP_SDA: J3.11, J21.1 (Pin_1_1)
/DISP_VCC: C20.1, C22.1, J3.5, J3.8, J19.1 (Pin_1_1), R13.1
GND: C14.2, C18.2, C20.2, C22.2, J3.7, J22.1 (Pin_1_1), R12.2
unnamed: C16.2, J3.1
unnamed: C16.1, J3.2
unnamed: C17.2, J3.3
unnamed: C17.1, J3.4
unnamed: J3.12, R12.1
unnamed: C14.1, J3.13
unnamed: C18.1, J3.14

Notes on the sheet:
C2N
SCL
RES#
C1P
IREF
C1N
C2P
VDD
OLED SCREEN
VCC
SDA
VBREF
OLED DISPLAY
VBAT
VSS
VCOMH
Possible Models: UG-9616TSWCG02 (Pinecil v2) 0x3C,0x3D X063-2028TSWIG02-H14 X069-9616TSWIG02-H14

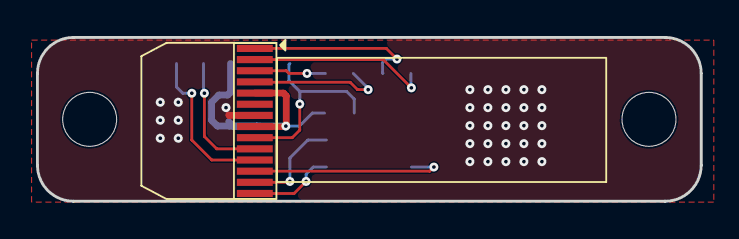
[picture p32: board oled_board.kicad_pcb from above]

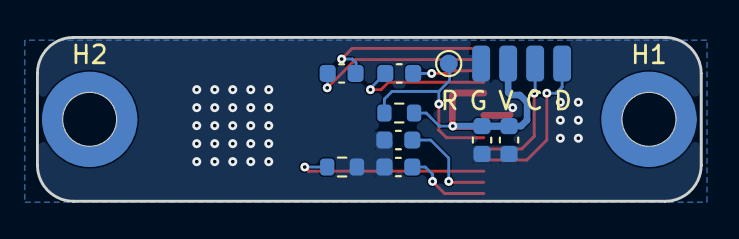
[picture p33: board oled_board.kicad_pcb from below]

Board: 2 copper layers, 36.9 x 9.1 mm, 16 parts (15 on the bottom side), 12 nets.

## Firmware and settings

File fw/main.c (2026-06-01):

#include <ch32fun.h>
#include <stdint.h>
#include <stdio.h>
#include <fsusb.h>

#include "funconfig.h"
#include "lib_i2c.h"
#include "display.h"
#include "filter.h"
#include "sc7a20.h"
#include "pd.h"
#include "ntc.h"
#include "fpmath.h"
#include "coroutine.h"


// Task timers
struct timer {
	uint32_t start, set;
};

// Set a timer, call timer_expired repeatedly to update it
static inline void timer_set(struct timer *t, uint32_t ms)
{
	t->start = funSysTick32();
	t->set = Ticks_from_Ms(ms);
}

// Check if enough time has passed from timer_set call
static inline bool timer_expired(struct timer *t)
{
	return funSysTick32() > (t->start + t->set);
}


// Button
struct button {
	bool now, prev;
};

static inline void button_init(struct button *btn, bool pullup)
{
	btn->now = btn->prev = pullup;
}

static inline void button_update(struct button *btn, bool state)
{
	btn->prev = btn->now;
	btn->now = state;
}

#define button_rising(btn) ((btn).now == true && (btn).prev == false)
#define button_falling(btn) ((btn).now == false && (btn).prev == true)


/* ------------------------------ Global State ------------------------------ */
u8g2_t *u8g2;                   // Display state
int16_t encoder;                // Rotary encoder counter
struct pd_profile_t pd_profile; // USB Power Delivery profile
uint16_t vcc_mv = 3300;         // Logic (and analog) voltage
uint16_t tip_mv;                // Tip amplifier reading in mV
uint16_t tip_temp_c;            // Converted tip temperature in degrees C
int16_t temp_c;                 // Board temperature in degrees C
uint16_t vbus_mv;               // USB bus voltage in mV
uint16_t current_ma;            // USB bus current to the heater in mA
uint16_t power;                 // Current power provided to the heater
uint16_t duty;                  // Current mosfet driver duty cycle (0-100%)
bool enabled = false;           // Power electronics enabled


// convert the raw TPA191 adc reading to a current in milliamps
static inline int16_t get_current_ma(uint16_t adc_reading)
{
	// Rshunt = 4 milliOhm
	// Gain = 100
	u32 mv = ((u32)adc_reading * vcc_mv) / 4096;
	return (mv * 10) / 4;
}


// this callback is mandatory when FUNCONF_USE_USBPRINTF is defined,
// can be empty though
void handle_usbfs_input(int numbytes, uint8_t *data)
{
	(void)numbytes;
	(void)data;
}


/*
 *    __      ____      ____
 * A:   |____|    |____|    |____
 *         ____      ____      __
 * B: ____|    |____|    |____|
 *      ^ ^  ^ ^  ^ ^  ^ ^  ^ ^
 *      f r  r f  f r  r f  f r
 *      |<---->| single detent
 */
void update_encoder(void)
{
	// 0 = 00, 1 = 01, 2 = 10, 3 = 11
	static uint8_t last_state = 0;
	static int8_t count;
	// Lookup table: state_table[last_state][current_state]
	//  0 = invalid move or bounce (ignore)
	//  1 = valid forward step
	// -1 = valid backward step
	static const int8_t state_table[4][4] = {
		{ 0,  1, -1,  0}, // from 00
		{-1,  0,  0,  1}, // from 01
		{ 1,  0,  0, -1}, // from 10
		{ 0, -1,  1,  0}  // from 11
	};

	// FIXME: even with interrupts disabled and debounce, a single detent triggers
	// multiple interrupts, leading to multiple encoder updates in a short time.
	if (funDigitalRead(PIN_BTN) == 0) return;
	bool a = funDigitalRead(PIN_ENC_A);
	bool b = funDigitalRead(PIN_ENC_B);
	Delay_Us(100);
	if (a != funDigitalRead(PIN_ENC_A) || b != funDigitalRead(PIN_ENC_B))
		return; // debounce

	uint8_t current_state = (a << 1) | b;

	// Find the movement direction based on transition
	count += state_table[last_state][current_state];

#if ENCODER_INV
	if (count == 4) encoder--, count = 0;
	if (count == -4) encoder++, count = 0;
#else
	if (count == 4) encoder++, count = 0;
	if (count == -4) encoder--, count = 0;
#endif

	// Save current state for the next interrupt
	last_state = current_state;
}

// Attached to PIN_ENC_A rising and falling edges
void EXTI7_0_IRQHandler(void) __attribute__((interrupt));
void EXTI7_0_IRQHandler(void)
{
	__disable_irq();
	update_encoder();
	EXTI->INTFR = EXTI_Line3;
	__enable_irq();
}

// Attached to PIN_ENC_B rising and falling edges
void EXTI15_8_IRQHandler(void) __attribute__((interrupt));
void EXTI15_8_IRQHandler(void)
{
	__disable_irq();
	update_encoder();
	EXTI->INTFR = EXTI_Line11;
	__enable_irq();
}


// Procedure to get hardware I2C working on the CH32X035F8U6
static inline void setup_i2c(void)
{
	// Order here matters, first initialize the AFIO and I2C subsystems then
	// change register values, do that the other way around and the configuration
	// wont take effect
	// Enable AFIO (Alternate Function IO)
	RCC->APB2PCENR |= RCC_AFIOEN;
	// Init I2C
	i2c_init(I2C_TARGET, FUNCONF_SYSTEM_CORE_CLOCK, 400000);

	// To utilize the I2C bus we need to disable SWD first, since the pins overlap
	AFIO->PCFR1 &= ~(0b0111 << 24);
	AFIO->PCFR1 |=   0b0100 << 24;

	// Map SCL to PC18 and SDA to PC19
	AFIO->PCFR1 |= 0b0101 << 2;
	// Manually set the I2C pins to Alternate Function IO,  CNF=10b, MODE=10b
	GPIOC->CFGXR &= ~((0xF << 8) | (0xF << 12)); // first clear the bits
	// then set them
	GPIOC->CFGXR |= 0b1010 << 8; // PC18
	GPIOC->CFGXR |= 0b1010 << 12; // PC19
}


volatile uint16_t adc_buffer[16];
// Set-up the adc to perform continous conversion of enabled channels, enable
// channel injection and setup DMA to automatically transfer conversion results
// to a buffer
static inline void setup_adc_and_dma(uint8_t *channels, uint8_t ch_size, uint8_t *injected, uint8_t in_size)
{
	if (channels == NULL || ch_size == 0) return;
	// FIXME: for now only support a single configuration register, so at max 6 channels
	//        I don't want to implement logic to switch registers right now
	// TODO: report an error
	if (ch_size > 6) return;

	// General ADC initialization, I use this only for enabling clocks and such
	funAnalogInit(); // general initialization

	// Set the SCAN and CONT bits to enter continous conversion mode
	// Do not set the IAUTO bit to ensure injected channels are converted only
	// when specified by software
	// Set the regular channel trigger mode to software (EXTSEL = 0b111) to ensure
	// conversion starts in sync with DMA (this should already be done by funAnalogInit())
	ADC1->CTLR1 |= ADC_SCAN;
	ADC1->CTLR2 |= ADC_CONT | ADC_EXTSEL;

	// Setup regular channels (scanned continously)
	// TODO: setup sampling time
	for (uint8_t i = 0; i < ch_size; i++) {
		// Increase sampling time to have less cross talk between channels
		// 0b111 means 11 ADC clock cycles (max)
		if (channels[i] < 10) {
			ADC1->SAMPTR2 |= 0b111 << (channels[i]*3);
		} else {
			ADC1->SAMPTR1 |= 0b111 << ((channels[i]-10)*3);
		}
		ADC1->RSQR3 |= channels[i] << (i*5);
	}
	// Set the number of normal conversion channels
	ADC1->RSQR1 |= (ch_size-1) << 20;

	// Set-up injection channels
	// The injection channel register allows for up to 4 channels, if the buffer is larger
	// skip this step
	// TODO: report an error
	if (injected != NULL && in_size != 0 && in_size <= 4) {
		// enable injection group
		// JEXTSEL = 0b111 (software trigger)
		ADC1->CTLR2 |= ADC_JEXTSEL;
		for (uint8_t i = 0; i < in_size; i++) {
			ADC1->ISQR |= injected[i] << ((4-in_size+i)*5);
		}
		// Set the number of injection channels
		ADC1->ISQR |= (in_size-1) << 20;
	}

	// Set-up DMA, ADC is connected only to channel 1
	// Turn on DMA
	RCC->AHBPCENR |= RCC_AHBPeriph_DMA1;
	// 1. Set the address of the source peripheral, in this case the output
	//    register of the ADC
	DMA1_Channel1->PADDR = (uint32_t)&(ADC1->RDATAR);
	// 2. Set the destination (base) address of the data
	DMA1_Channel1->MADDR = (uint32_t)adc_buffer;
	// 3. Set the number of transfers to be done each cycle, in this case it's
	//    the same as the number of regular conversion cycles
	DMA1_Channel1->CNTR = ch_size;
	// 4. Set mode: Peripheral to Memory, MEM2MEM=0 DIR=0
	//    Circular mode CIRC=1, restart after CNTR transfers
	//    Max priority to not lose conversions and offset values in the buffer
	DMA1_Channel1->CFGR  =
		DMA_M2M_Disable |
		DMA_Priority_VeryHigh |
		DMA_MemoryDataSize_HalfWord |
		DMA_PeripheralDataSize_HalfWord |
		DMA_MemoryInc_Enable |
		DMA_Mode_Circular |
		DMA_DIR_PeripheralSRC;
	// Turn on DMA channel 1
	DMA1_Channel1->CFGR |= DMA_CFGR1_EN;

	// Enable DMA requests from the ADC
	ADC1->CTLR2 |= ADC_DMA;
	// Power up ADC again
	ADC1->CTLR2 |= ADC_ADON;
	// start conversion
	ADC1->CTLR2 |= ADC_SWSTART;
}


// Perform a conversion on the injected ADC channels, this is synchronous and
// halts conversion on the normal channels until it completes
volatile uint16_t injection_results[4];
static inline bool adc_injection_conversion() {
	// Clear any pending flags
	ADC1->STATR &= ~(ADC_JEOC);

	// Start injection conversion using external trigger method
	ADC1->CTLR2 |= ADC_JSWSTART;

	// Wait for all conversions to complete
	s32 timeout = 1000000;
	while(!(ADC1->STATR & ADC_JEOC) && timeout--) {}

	if (timeout <= 0) return false;

	// Read all results
	injection_results[0] = ADC1->IDATAR1 & 0x0FFF;
	injection_results[1] = ADC1->IDATAR2 & 0x0FFF;
	injection_results[2] = ADC1->IDATAR3 & 0x0FFF;
	injection_results[3] = ADC1->IDATAR4 & 0x0FFF;

	// Clear JEOC flag
	ADC1->STATR &= ~ADC_JEOC;

	return true;
}

// mask for the CCxP bits
// when set PWM outputs are held HIGH by default and pulled LOW
// when zero PWM outputs are held LOW by default and pulled HIGH
// #define TIM3_DEFAULT 0xff
#define TIM3_DEFAULT 0x00
static inline void setup_pwm(void)
{
	// Enable TIM3 clock
	RCC->APB1PCENR |= RCC_APB1Periph_TIM3;

	// Since TIM3 is enabled with TIM3->SMCFGR.SMS = 0b000 (default value) the
	// clock source is the internal clock
	// The internal clock goes through the HBB prescaler RCC->CFGR0.HPRE which
	// by default is disabled

	// Reset TIM3 to init all regs
	RCC->APB1PRSTR |= RCC_APB1Periph_TIM3;
	RCC->APB1PRSTR &= ~RCC_APB1Periph_TIM3;

	// set TIM3 clock prescaler divider
	TIM3->PSC = 0x0000; // no prescaler
	// set PWM total cycle width
	static_assert((FUNCONF_SYSTEM_CORE_CLOCK / PWM_FREQ_HZ - 1) < 0xffff, "PWM_FREQ_HZ too low for TIM3");
	TIM3->ATRLR = FUNCONF_SYSTEM_CORE_CLOCK / PWM_FREQ_HZ - 1;

	// for channel 1 let CCxS stay 00 (output), set OC1M to 110 (PWM 1)
	// enabling preload (OC1PE) causes the new pulse width in compare capture
	// register only to come into effect when UG bit in SWEVGR is set
	// (= initiate update) (auto-clears)
	TIM3->CHCTLR1 |= TIM_OC1M_2 | TIM_OC1M_1 | TIM_OC1PE;

	// Enable channel 1 output (PA6)
	TIM3->CCER |= TIM_CC1E | ( TIM_CC1P & TIM3_DEFAULT );

	// CTLR1: default is up, events generated, edge align
	// enable auto-reload of preload
	TIM3->CTLR1 |= TIM_ARPE;
}


static inline void pwm_on(void)
{
	// initialize counter
	TIM3->SWEVGR |= TIM_UG;
	// Enable TIM3
	TIM3->CTLR1 |= TIM_CEN;
}


static inline void pwm_off(void)
{
	// Disable TIM3
	TIM3->CTLR1 &= ~TIM_CEN;
	TIM3->CH1CVR = 0;
}


static inline void pwm_set(uint16_t pulse_width)
{
	TIM3->CH1CVR = pulse_width;
}


// Input: temperature difference
// Output: duty-cycle 0-max_duty
uint16_t pid(int16_t delta, int16_t max_duty)
{
	// PID coefficients
	const fp16_t Kp = num2fp( 1, 1700, 4);
	const fp16_t Ti = num2fp(10, 0000, 4);
	const fp16_t Td = num2fp( 0, 1500, 4);

	static fp16_t err_p, err_i, intgrt, err_d, dt, prev_err;
	static u32 t, prev_t;

	t = funSysTick32();
	dt = fp_div(i2fp((t-prev_t)/DELAY_MS_TIME), i2fp(1000));

	// if pid was paused, reset the integrator
	if (dt > num2fp(0, 2, 1)) intgrt = 0;

	fp16_t err = i2fp(delta); // temperature delta as fixed point number

	err_p = err;
	err_i = fp_mul(fp_div(err, Ti), dt);
	err_d = fp_mul(fp_div(fp_sub(err, prev_err), dt), Td);

	prev_err = err;
	prev_t = t;

	fp16_t e = 0;
	e = fp_add(e, err_p);
	e = fp_add(fp_add(e, err_i), intgrt);
	e = fp_add(e, err_d);
	e = fp_mul(e, Kp);

	// TODO: use a back calculation anti windup strategy
	// only integrate if the output is less then max
	if (e < i2fp(100) && e > 0) {
		intgrt = fp_add(intgrt, err_i);
	}

	e = fp_clamp(e, i2fp(0), i2fp(100));

	// TODO: implement minimum duty cycle
	return fp2i(fp_map(e, 0, i2fp(100), 0, i2fp(max_duty)));
}


/* ------------------------------ Board Setup ------------------------------- */
static inline void setup(void)
{
	// Generic system setup
	SystemInit();
	funGpioInitAll();
	USBFSSetup();

	// ====================== Analog pin configuration ====================== //
	funPinMode(PIN_VBUS, GPIO_CFGLR_IN_ANALOG);
	funPinMode(PIN_CURRENT, GPIO_CFGLR_IN_ANALOG);
	funPinMode(PIN_NTC, GPIO_CFGLR_IN_ANALOG);
	funPinMode(PIN_TEMP, GPIO_CFGLR_IN_ANALOG);

	// Analog inputs setup (dma and injection conversion)
	uint8_t adc_channels[] = {
		VBUS_ADC_CHANNEL,
		CURRENT_ADC_CHANNEL,
		NTC_ADC_CHANNEL
	};
	uint8_t adc_injected[] = {
		TEMP_ADC_CHANNEL,
		VREF_INT_CHANNEL
	};
	setup_adc_and_dma(adc_channels, sizeof(adc_channels), adc_injected, sizeof(adc_injected));

	// ====================== Digital pin configuration ===================== //
	funPinMode(PIN_12V, GPIO_CFGLR_OUT_10Mhz_PP);
	funDigitalWrite(PIN_12V, 0);
	funPinMode(PIN_HEATER, GPIO_CFGLR_OUT_10Mhz_AF_PP);
	funDigitalWrite(PIN_HEATER, 0);
	funPinMode(PIN_DISP_RST, GPIO_CFGLR_OUT_10Mhz_PP);
	funDigitalWrite(PIN_DISP_RST, 1);

	funPinMode(PIN_ENC_A, GPIO_CFGLR_IN_PUPD); // enable pull-up/down
	funDigitalWrite(PIN_ENC_A, 1);             // specify pull-up
	funPinMode(PIN_ENC_B, GPIO_CFGLR_IN_PUPD); // enable pull-up/down
	funDigitalWrite(PIN_ENC_B, 1);             // specify pull-up
	funPinMode(PIN_BTN, GPIO_CFGLR_IN_FLOAT);

	// Setup PWM timer, includes pin setup
	setup_pwm();
	pwm_off();

	// =========================== Encoder Setup ============================ //
	// Configure the IO as an interrupt.
	// PIN_ENC_B is on port B, channel 11
	AFIO->EXTICR1 |= AFIO_EXTICR1_EXTI11_PB; // Port B channel (pin) 11
	EXTI->INTENR |= EXTI_INTENR_MR11;        // Enable EXT11
	EXTI->FTENR |= EXTI_FTENR_TR11;          // Falling edge trigger
	EXTI->RTENR |= EXTI_RTENR_TR11;          // Rising edge trigger
	// enable interrupt
	NVIC_EnableIRQ(EXTI15_8_IRQn);

	// PIN_ENC_A is on port B, channel 3
	AFIO->EXTICR1 |= AFIO_EXTICR1_EXTI3_PB; // Port B channel (pin) 3
	EXTI->INTENR |= EXTI_INTENR_MR3;        // Enable EXT3
	EXTI->FTENR |= EXTI_FTENR_TR3;          // Falling edge trigger
	EXTI->RTENR |= EXTI_RTENR_TR3;          // Rising edge trigger
	// enable interrupt
	NVIC_EnableIRQ(EXTI7_0_IRQn);

	// ============================= I2C Setup ============================== //
	// Setup i2c line, includes setting the pin alternate mode
	setup_i2c();
	// Start i2c peripherals
	u8g2 = display_init();
	sc7a20_init();
}


// Update the global istantaneous voltage, current, power and board temperature
// this requires the automatic conversion (ADC+DMA) to be running
static inline void update_power_and_temperature(void)
{
	// Voltage current and power
	vbus_mv    = U16_FP_EMA_K4(vbus_mv, ((u32)adc_buffer[0]*vcc_mv*11)/4096);
	current_ma = U16_FP_EMA_K4(current_ma, get_current_ma(adc_buffer[1]));
	power      = ((u32)vbus_mv*current_ma)/1000000;
	// Board temperature
	temp_c     = I16_FP_EMA_K4(temp_c, get_temp_c(adc_buffer[2]));
}


// Update VCC and the tip temperature, both are sampled with injection conversion
// so it is triggered in this function
static inline void update_tip_and_vcc(void)
{
	// Tip calibration factors
	const fp16_t tip_k = num2fp(0, 14473, 5);
	const fp16_t tip_off = num2fp(0, 0, 0);

	adc_injection_conversion();
	// Calibrate VCC with the internal reference value
	vcc_mv = I16_FP_EMA_K4(vcc_mv, ((uint32_t)1200 * 4096)/injection_results[1]);

	uint16_t tip_mv = ((u32)injection_results[0]*vcc_mv)/4096;
	int16_t tt_now  = fp2i(fp_add(fp_mul(i2fp(tip_mv), tip_k), tip_off));
	// Tip temp with cold-junction compensation, assume the board temperature is
	// the same as the cold junction, on an external handle this is not always true
	tip_temp_c = I16_FP_EMA_K4(tip_temp_c, tt_now + temp_c);
}


// coroutine to draw the "main" ui which draws the current tip temperature, power
// pwm state, etc.
coro_state_t cs_ui;
coroutine c_draw_main_ui(coro_state_t *state)
{
	static struct timer t;
	coro_begin(state);

	for(;;) {
		// Wait for the next frame, roughly 30 fps
		timer_set(&t, 33);
		coro_wait_until(state, timer_expired(&t));

		// Draw UI
		u8g2_ClearBuffer(u8g2);
		u8g2_SetFont(u8g2, u8g2_font_5x8_tr);
		draw_temp(u8g2, x_off+0, y_off+0, tip_temp_c, true);
		u8g2_DrawStr(u8g2, x_off+32, y_off+6, "A:");
		u8g2_DrawStr(u8g2, x_off+42, y_off+6, u16toa((current_ma+500)/1000));
		u8g2_DrawStr(u8g2, x_off+60, y_off+6, "V:");
		u8g2_DrawStr(u8g2, x_off+70, y_off+6, u16toa((vbus_mv+500)/1000));
		uint8_t p = (power*100)/pd_profile.set_power;
		uint8_t w = (uint16_t)(p*54)/100;
		u8g2_DrawBox(u8g2, x_off+42, y_off+14, w, 5);
	}

	coro_end();
}


// coroutine to update the tip temperature, vcc and compute the new pid value
// this has to be called periodically but only with pwm disabled
coro_state_t cs_duty;
coroutine c_update_duty(coro_state_t *state)
{
	static struct timer t;
	coro_begin(state);

	for(;;) {
		timer_set(&t, 50);
		coro_wait_until(state, timer_expired(&t));

		pwm_set(0);
		Delay_Ms(TURN_OFF_DELAY);
		update_tip_and_vcc();
		if (enabled) {
			duty = pid((int16_t)pd_profile.set_temp - tip_temp_c, pd_profile.max_duty);
		} else {
			duty = 0;
		}
	}

	coro_end();
}


__attribute__((noreturn)) int main(void)
{
	setup();

	coro_init(&cs_ui);
	coro_init(&cs_duty);

	u8g2_ClearBuffer(u8g2);
	u8g2_SetFont(u8g2, u8g2_font_5x8_tr);
	u8g2_DrawStr(u8g2, x_off+0, y_off+7, "Negotiating...");
	u8g2_SendBuffer(u8g2);

	// Init USBPD
	bool has_pd = pd_negotiate(eUSBPD_VCC_3V3);
	if (has_pd == false) {
		while (true) {
			// No Power Delivery, maybe we are attached to a computer, so poll the input
			poll_input();

			update_power_and_temperature();
			update_tip_and_vcc();

			u8g2_ClearBuffer(u8g2);
			u8g2_SetFont(u8g2, u8g2_font_5x8_tr);
			u8g2_DrawStr(u8g2, x_off+0, y_off+7, "Negotiation FAILED");
			u8g2_DrawStr(u8g2, x_off+0, y_off+14, USBPD_ResultToStr(pd_get_result()));
			u8g2_DrawStr(u8g2, x_off+0, y_off+21, u16toa(vcc_mv));
			u8g2_DrawStr(u8g2, x_off+0, y_off+28, u16toa(temp_c));
			u8g2_DrawStr(u8g2, x_off+30, y_off+28, u16toa(tip_temp_c));
			u8g2_SendBuffer(u8g2);
		}
	} else {
		pd_get_profile(&pd_profile, 100);

		// TODO: let the user decide the power profile
		pd_profile.set_temp = 320;
		pd_profile.set_power = 95; // Slightly below max power to avoid overloading
		pd_profile.tip_r = 2500; // TODO: tip check and resistance calculator
		pd_profile.max_duty = MIN(
			(100*(u32)isqrt((
				MIN(pd_profile.set_power, pd_profile.power_avail)*pd_profile.tip_r)/1000) * 1000) / pd_profile.voltage
			, 100);
	}


	enum {
		STATE_MENU,
		STATE_HEATING,
	} state = STATE_MENU;

	/* ============================== Main Loop =============================== */
	struct button btn;
	button_init(&btn, true);
	for (;;) {
		button_update(&btn, funDigitalRead(PIN_BTN));

		update_power_and_temperature();

		c_update_duty(&cs_duty);

		switch (state) {
		case STATE_MENU:
			u8g2_ClearBuffer(u8g2);
			u8g2_SetFont(u8g2, u8g2_font_5x8_tr);
			u8g2_DrawStr(u8g2, x_off+0, y_off+7, "TEMP:");
			u8g2_DrawStr(u8g2, x_off+25, y_off+7, u8g2_u16toa(pd_profile.set_temp, 4));

			if (encoder != 0) {
				pd_profile.set_temp += encoder >= ENCODER_FAST ? 20 : encoder;
				encoder = 0;
				if (pd_profile.set_temp < MIN_TIP_SET_TEMP) pd_profile.set_temp = MIN_TIP_SET_TEMP;
				if (pd_profile.set_temp > MAX_TIP_SET_TEMP) pd_profile.set_temp = MAX_TIP_SET_TEMP;
			}

			if (button_falling(btn)) {
				state = STATE_HEATING;
				enabled = false;
			}
			break;
		case STATE_HEATING:
			c_draw_main_ui(&cs_ui);

			if (enabled) {
				funDigitalWrite(PIN_12V, 1);

				// Safety logic
				if (current_ma > pd_profile.max_current + pd_profile.max_current/10) {
					enabled = false;
				}
				if (temp_c > MAX_BOARD_TEMP) {
					enabled = false;
				}
				if (tip_temp_c > MAX_TIP_TEMP) {
					enabled = false;
				}

				const uint16_t tim_max = FUNCONF_SYSTEM_CORE_CLOCK / PWM_FREQ_HZ - 1;
				pwm_set(((u32)duty*tim_max)/100);
				u8g2_DrawBox(u8g2, x_off+92, y_off+0, 4, 4);
			} else {
				funDigitalWrite(PIN_12V, 0);
			}

			// move to menu mode when encoder is turned
			if (encoder != 0) {
				state = STATE_MENU;
				funDigitalWrite(PIN_12V, 0);
				pwm_set(0);
			}

			// Check button to toggle enable
			if (button_falling(btn)) {
				enabled = !enabled;
				if (enabled) {
					pwm_on();
				} else {
					pwm_off();
				}
			}
			break;
		}
		u8g2_SendBuffer(u8g2);
	}
}

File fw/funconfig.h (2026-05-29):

#ifndef _FUNCONFIG_H
#define _FUNCONFIG_H

#define FUNCONF_USE_DEBUGPRINTF 0 // can only have one printf
#define FUNCONF_USE_USBPRINTF   1
#define FUNCONF_DEBUG_HARDFAULT 0
#define CH32X035                1
#define I2C_TARGET              I2C1
#define FRAME_TIME_MS           20 // 50Hz
#define PWM_FREQ_HZ             100000 // TIM3 PWM frequency

// Pin definitions
#define PIN_VBUS     PA0  // vbus voltage feedback
#define PIN_CURRENT  PA1  // current feedback
#define PIN_NTC      PA2  // ntc temperature sensor
#define PIN_TEMP     PA3  // thermocouple amplifier
#define PIN_12V      PA5  // 12V regulator enable
#define PIN_HEATER   PA6  // power mosfet gate control
#define PIN_ENC_A    PB3  // rotary encoder A
#define PIN_ENC_B    PB11 // rotary encoder B
#define PIN_BTN      PB1  // rotary encoder button

// Analog channel definitions
#define VBUS_ADC_CHANNEL    ANALOG_0 // PA0
#define CURRENT_ADC_CHANNEL ANALOG_1 // PA1
#define NTC_ADC_CHANNEL     ANALOG_2 // PA2
#define TEMP_ADC_CHANNEL    ANALOG_3 // PA3
#define VREF_INT_CHANNEL    15       // Internal channel set to 1.2V reference

#define ENCODER_INV true
#define ENCODER_FAST 3

#define MAX_BOARD_TEMP 50
#define MAX_TIP_TEMP   500
#define TURN_OFF_DELAY 3
#define CYCLES_PER_MEASURE 2
#define BOARD_MAX_VOLTAGE 28000
#define MIN_TIP_SET_TEMP 100
#define MAX_TIP_SET_TEMP 420



#endif // _FUNCONFIG_H

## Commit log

2026-01-16 board dimensions and different components
    [usbc_soldering_iron.kicad_pcb, usbc_soldering_iron.kicad_sch]
2026-01-16 some things needed to be 0805
    [usbc_soldering_iron.kicad_pcb, usbc_soldering_iron.kicad_sch]
2026-01-20 progress on schematic and ui draft
    [usbc_soldering_iron.kicad_pcb, usbc_soldering_iron.kicad_sch]
2026-01-20 mosfet protection and low side current sensing
    [usbc_soldering_iron.kicad_pcb, usbc_soldering_iron.kicad_sch]
2026-01-20 removed LED and added NTC
    [usbc_soldering_iron.kicad_pcb, usbc_soldering_iron.kicad_sch]
2026-01-22 added tip 3d model
    [c245-903.FCStd]
2026-01-22 update model to freecad stable version
    [c245-903.FCStd]
2026-01-22 added pads for tip connector
    [usbc_soldering_iron.kicad_pcb, usbc_soldering_iron.kicad_sch]
2026-01-24 big update
    * drawn contacts
    * done board outline in cad
    * reverted to high-side monitoring with ad-hoc ic
    [c245-903.FCStd, usbc_soldering_iron.kicad_pcb, usbc_soldering_iron.kicad_sch]
2026-01-24 FIX MOSFET ORIENTATION
    [usbc_soldering_iron.kicad_sch]
2026-02-03 excel dei buck
    [buck_ics.ods]
2026-02-03 stima della massima potenza dissipata
    [buck_ics.ods]
2026-02-07 buck converter
    [usbc_soldering_iron.kicad_pcb, usbc_soldering_iron.kicad_sch]
2026-02-07 ltspice simulations
    [buck_ics.ods]
2026-02-13 mosfets and driver
    [usbc_soldering_iron.kicad_pcb, usbc_soldering_iron.kicad_sch]
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2026-02-14 different mosfets
    [usbc_soldering_iron.kicad_sch]
2026-02-17 complete model test
    [3DModel.FCStd]
2026-02-18 work on model
    [3DModel.FCStd, usbc_soldering_iron.kicad_pcb, usbc_soldering_iron.kicad_sch]
2026-02-18 rotary encoder and model for usb receptacle
    [3DModel.FCStd, GT-USB-7016D.step, GT-USB-7025.step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]
2026-02-18 started work on report
    [c245-903.FCStd]
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2026-02-19 changed power stage and monitoring ICs
    [usbc_soldering_iron.kicad_pcb, usbc_soldering_iron.kicad_sch]
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2026-02-22 separate boost for gate driver
    [usbc_soldering_iron.kicad_pcb, usbc_soldering_iron.kicad_sch]
2026-02-22 removed i2c temp sensor and high side bus switch
    [usbc_soldering_iron.kicad_pcb, usbc_soldering_iron.kicad_sch]
2026-02-22 preliminary BOM and schematic
    [bom_preliminary_lcsc.csv, usbc_soldering_iron.kicad_sch]
2026-02-22 fixed buck, same family
    [usbc_soldering_iron.kicad_pcb, usbc_soldering_iron.kicad_sch]
2026-02-24 revised schematic
    - changed mcu to ch32x035
    - removed fusbxx pd controller, since it's integrated into the mcu
    - reverted the ina226 to the tpa191
    - removed temperature sensor in favor of an ntc
    - routed tip contacts correctly
    [usbc_soldering_iron.kicad_pcb, usbc_soldering_iron.kicad_sch]
2026-02-24 bom for revised schematic
    [bom_preliminary_lcsc.csv]
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2026-02-25 flyback diode to the tip
    [bom_preliminary_lcsc.csv, usbc_soldering_iron.kicad_pcb, usbc_soldering_iron.kicad_sch]
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2026-02-26 removed the diocane filter in favor of capacitors
    [bom_preliminary_lcsc.csv, usbc_soldering_iron.kicad_pcb, usbc_soldering_iron.kicad_sch]
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2026-02-28 Revert "trying new capacitors"
    This reverts commit 6cb91291f39b019d0baab4303cfee70c88c38332.
    [usbc_soldering_iron.kicad_pcb, usbc_soldering_iron.kicad_sch]
2026-02-28 Revert "different capacitors in sim with pi filter"
    This reverts commit 30c0aa5cba112ce18ca016d04ddbcca1eab52d60.
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2026-02-28 different capacitors and new bom
    [bom_preliminary_lcsc.csv, usbc_soldering_iron.kicad_pcb, usbc_soldering_iron.kicad_sch]
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2026-03-02 new filter design, may work lmao
    [bom_preliminary_lcsc.csv, usbc_soldering_iron.kicad_pcb, usbc_soldering_iron.kicad_sch]
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2026-03-09 switch-off simulations and in-stock capacitors
    [bom_preliminary_lcsc.csv]
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2026-03-21 3D model of first enclosure
    [3DModel.FCStd, Enclosure-Cap.step, Enclosure-Shell.step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]
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2026-03-25 updated to kicad 10.0
    [usbc_soldering_iron.kicad_pcb, usbc_soldering_iron.kicad_sch]
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2026-04-18 scan correct I2C bus
    [main.c]
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2026-04-19 added fixed point exponential average filters
    [main.c]
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2026-04-19 correct use of #if defined check
    [display.c]
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2026-05-01 reverted pwm frequency to 100khz
    Also recompile on header change
    [funconfig.h]
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2026-05-10 fix delta calc to signed
    [main.c]
2026-05-10 use FR_math for fixed point arithmetic
    [main.c]
2026-05-11 fix encoder
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2026-05-14 hand rolled fixed point math
    [main.c]
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2026-05-16 tweak pid for less overshoot
    [main.c]
2026-05-24 changed inductor footprint to correct one
    [usbc_soldering_iron.kicad_pcb, usbc_soldering_iron.kicad_sch]
2026-05-24 input capacitors near boost
    [usbc_soldering_iron.kicad_pcb, usbc_soldering_iron.kicad_sch]
2026-05-24 ref of tpa191 to gnd
    [usbc_soldering_iron.kicad_pcb, usbc_soldering_iron.kicad_sch]
2026-05-24 corrected tlv333 pin assignment
    [usbc_soldering_iron.kicad_pcb, usbc_soldering_iron.kicad_sch]
2026-05-24 5.1k resistors in cc1/2
    [usbc_soldering_iron.kicad_pcb, usbc_soldering_iron.kicad_sch]
2026-05-25 debounce caps on encoder and silkscreen adj
    [usbc_soldering_iron.kicad_pcb, usbc_soldering_iron.kicad_sch]
2026-05-26 removed diode in programming header
    [usbc_soldering_iron.kicad_pcb, usbc_soldering_iron.kicad_sch]
2026-05-26 more capacitors in main buck
    [usbc_soldering_iron.kicad_pcb, usbc_soldering_iron.kicad_sch]
2026-05-26 better protection diode for tlv333
    [usbc_soldering_iron.kicad_pcb, usbc_soldering_iron.kicad_sch]
2026-05-27 new footprint for big inductor
    [usbc_soldering_iron.kicad_pcb, usbc_soldering_iron.kicad_sch]
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2026-05-29 lower tolerance in ntc pullup
    [usbc_soldering_iron.kicad_sch]
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2026-06-02 started work on integrated pcb
    [usbc_soldering_iron.kicad_pcb, usbc_soldering_iron.kicad_sch]
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2026-06-12 vias around tip contacts
    [usbc_soldering_iron.kicad_pcb]
2026-06-14 moved models to appropriate directory
    [Housing.FCStd, Housing_V2.FCStd, Housing_V2_1.FCStd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]
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2026-06-14 removed oled from main board
    [usbc_soldering_iron.kicad_pcb, usbc_soldering_iron.kicad_sch]
2026-06-16 3d files and oled board
    [Housing_V3.FCStd, main_board.step, oled_board.kicad_pcb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]
2026-06-20 tv333 filter and BOM
    [bom_preliminary_lcsc.csv, usbc_soldering_iron.kicad_sch]
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2026-06-23 enlarged for new heatsink
    [Housing_V3.FCStd, c245-903-Tip.step]
2026-06-23 minor touch-ups on PCB
    [usbc_soldering_iron.kicad_pcb]
2026-06-26 silkscreen and better contacts
    [usbc_soldering_iron.kicad_pcb]
2026-06-26 new outline and shell
    [Housing_V3.FCStd, board.FCStd, main_board.step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]
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2026-06-27 tighter fit on back side of board
    [Housing_V3.FCStd]
2026-06-28 BOM tweaks and distilled for order
    [bom_preliminary_lcsc.csv, order_2.csv]
2026-06-30 programming hole on bottom
    [Housing_V3.FCStd]
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2026-08-06 fix: housign would not close
    [Housing_V3.FCStd]
2026-09-17 3d printed enclosure tweaks
    [Housing_V3.FCStd]
